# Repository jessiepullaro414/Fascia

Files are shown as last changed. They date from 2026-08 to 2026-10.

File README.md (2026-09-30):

# Fascia — KiCad schematic + PCB

Companion KiCad project for "Fascia", a 10-inch Android Automotive touch
display head unit: sibling to
[`manifold-pcb`](https://github.com/jessiepullaro414/Manifold),
[`thermo-pcb`](https://github.com/jessiepullaro414/Thermo) and `ecu-pcb`,
same 12V automotive constraints as the rest of the family.

Unlike the rest of the family this is a **two-board** project, because the
panel is physically detached from the main board and sits across the dash
from it:

1. **Carrier board** (behind the dash) — a Toradex Verdin iMX95 System on
   Module on a custom carrier: automotive 12V front end, LVDS display
   output via a DSI-to-LVDS bridge, backlight control, CAN FD to talk to
   `ecu-pcb`, line-level audio pre-outs to an external amplifier, a
   microphone input, and USB-C for wired CarPlay / Android Auto.
2. **Panel board** (in the bezel) — terminates the ribbon at the screen:
   panel LVDS connector, capacitive touch controller, backlight LED
   connector.

Bluetooth and Wi-Fi need no carrier hardware — they come with the
module's `WB` variant.

## Status

**PCB placed and routed to within 3 connections.**
`build_pcb.py` generates `Fascia.kicad_pcb`: 118 footprints, 574 pads
netted across 129 nets, six layers, on a **148 x 71 mm** board.
`route_board.py` (ported from the sibling boards) routes it with
FreeRouting, widens the power trunks, pours GND on In1 and In4, and then
asks `kicad-cli` DRC how many connections are really open. After a
150-pass run **3 connections are still unrouted**: `AOUT_RL_N` (codec to
the audio connector), `U9_ADR1_TIE`, and `LVDS_A_Y0N` (bridge to panel
connector). FreeRouting oscillated between 3 and 4 for the last 100
passes, so more passes of the same run will not close them; they need a
second stochastic attempt or hand-routing. `run_drc.py` reports
**schematic parity 0**, 12 `lib_footprint_mismatch` findings that are a
KiCad tooling artifact, and one silkscreen-over-mask finding.

Nothing about the differential pairs is tuned: FreeRouting does not
length-match, so the DSI and dual-link LVDS pairs are ordinary routed
nets with no impedance control. `route_board.py` prints the resulting
intra-pair skew so it is a number, not a guess.

Placement uses the **same skyline bottom-left packer as `manifold-pcb`
and `thermo-pcb`**, ported rather than reinvented, with three additions
this board needed:

- **Every part is tried both unrotated and rotated 90 degrees**, and goes
  wherever it yields the lowest resulting top edge. That is what turns
  the tall pin-header connectors on their sides and lets the 0603s
  backfill the low spots beside the big parts.
- **Keepouts are real packer inputs**, not checks applied afterwards.
- **The bridge, socket and panel connector are placed first** (`PIN_FIRST`
  in `build_pcb.py`), so the DSI-to-LVDS bridge sits beside the Verdin
  socket instead of 75 mm away. Area order alone had put it there, and
  nearly every open net in the first routing run was at that bridge.
- **A passive goes near its own IC** (`PULL`). Once its anchor IC is
  down, a passive takes the slot closest to it, with a height penalty so
  it cannot strand a void below. Plain lowest-gap order had put a
  pull-up 130 mm from the chip it belongs to. Estimated wirelength fell
  from 7,612 to 5,895 mm (`tools/placement_metric.py`), and FreeRouting
  at 12 passes went from 22 unrouted to 4.
- Spacing between parts (`CLEAR`) is 2.0 mm, up from 1.3. That alone took
  12-pass routing from 22 unrouted to 11, at a cost of 7 mm of height.

Group membership is derived from the netlist: each part joins whichever
IC or connector it shares the most **non-rail** nets with. Rails are
excluded deliberately: GND touches everything and would make every part
look equally related to everything else.

The Verdin socket is rotated 90 degrees as part of that. Its footprint is
36 x 79 mm, tall and narrow; on its side it is 79 x 36 mm and the board
becomes landscape, which is also the shape a dash opening wants.

**Schematic complete — every block wired except the backlight.**
`build_schematic.py` generates a real, KiCad-loadable schematic
containing the Verdin iMX95 X1 connector, the 12 V automotive front end,
the 5 V buck, the 1.8 V and 3.3 V rails, CAN FD, the SN65DSI85-Q1
DSI-to-LVDS bridge, the PCM3168A-Q1 audio subsystem with its level
shifters, the USB-C port, and the control/sequencing block. No PCB yet.

`kicad-cli sch erc` reports **10 violations**, and every one is either
blocked on a datasheet that has not arrived or deliberately optional:

| What | Count | Why it is still open |
| --- | --- | --- |
| `PWM_3_DSI`, `GPIO_10_DSI` | 2 | Backlight — needs the iFan string voltage and current |
| `USB_2_*` | 4 | Panel touch link — needs the panel's touch interface confirmed |
| `CAN_2_*` | 2 | Optional second CAN bus; no consumer chosen |
| `DSI_IRQ` | 1 | Bridge interrupt; wants a spare 1.8 V module GPIO |
| `IGN_SENSE` | 1 | Ignition sense; wants a module ADC input |

**160 pins carry real NoConnect items and 40 signal nets are wired.**

**Footprints are assigned and verified.** Every part maps to a real
footprint, and the build checks that each named file actually exists — a
mistyped library path is otherwise invisible until the netlist reaches
the PCB editor and silently drops the part.

### The LM61460-Q1 footprint is generated, not borrowed

TI's RJR0014A (VQFN-HR-14) has no KiCad library footprint, and it is not
something a generic QFN generator can produce: the pads are all different
sizes, unevenly spaced, and **the four corner pads are L-shaped**.

`tools/build_lm61460_footprint.py` builds it. The geometry is not
eyeballed off the drawing — the LAND PATTERN EXAMPLE on page 55 of TI
SNVSB70F is real vector art, so the pad rectangles were extracted from
the PDF's own path data and only the *scale* had to be inferred, from a
dimension the drawing states outright (pad 10 is 2.4 × 0.4 mm). That
scale then reproduced pad 10's 0.400 mm height exactly, which is what
makes the rest of the extraction trustworthy.

Each L-shaped pad is built from **two rectangles sharing one pad
number** — a real KiCad construction this project has met before, in a
Keystone fuse holder with two physical pads both numbered "1". It is far
safer than approximating an L with its bounding box, which would put
copper in the notch and eat the clearance to the neighbouring pads.

All four notches face the *outer* corner of the pattern, confirmed by
rendering the drawing around pads 1, 9 and 11 rather than assuming the
symmetry held.

The generator verifies itself twice: internally, that the pad table is
coherent (pin numbering, which pads are L-shaped, pad 10's dimensions,
overall extent, and that no two *different* pins overlap), and then by
**loading the result back through KiCad's own engine**. That second check
earned its place immediately — the first version emitted trailing
`; PINNAME` comments on the pad lines, and KiCad's s-expression format
has no comment syntax, so the whole library failed to load with nothing
more useful than "Unable to load library".

The Verdin module plugs into a standard DDR4 SODIMM socket, and KiCad's
`SODIMM-260_DDR4_H4.0-5.2_OrientationStd_Socket` has exactly 260 pads
numbered 1–260 — a direct match for the extracted pinout, so the biggest
footprint risk on this board turned out to be no risk at all.

### Exposed pads are three different decisions

Every one of these footprints numbers its exposed pad N+1 — 65 on the
TQFP-64s, 25 on the VQFN-24, 9 on the SON-8s. Each symbol therefore
carries an explicit `EP` pin, so what happens to that pad is a visible
decision on the schematic rather than an accident of the pad having no
net:

| Part | Exposed pad |
| --- | --- |
| **LM74930-Q1** | **NoConnect — must float.** The datasheet forbids grounding it |
| TLV767-Q1, TPS2557-Q1 | GND |
| SN65DSI85-Q1, PCM3168A-Q1 | GND (PowerPAD is reference ground) |

The LM74930-Q1's NoConnect is load-bearing: without an explicit pin,
that pad is merely netless, and nothing on the drawing would stop a
later ground-stitching pass from claiming it.

What is already final:

- all 260 X1 pins exist, banked into 6 units
- 47 GND pins tied to ground, 5 VCC pins tied to +5V
- 158 unused pins carrying real `NoConnect` items
- **LM74930-Q1 front end fully wired** — back-to-back FETs with `A` and
  `OUT` on the shared source node, sense resistor with its 50 Ω tap into
  `CS+`, `OVCLAMP` tied to `OV` for clamp-with-breaker rather than plain
  disconnect, and the OV/UVLO dividers, timer, ILIM and IMON networks
- **LM61460-Q1 5 V buck fully wired** — `BIAS` to the output rail (valid
  because Vout ≤ 12 V), boot network through `RBOOT`, FB and EN dividers,
  `RT`, and pull-ups on the open-drain `FLT` and `PGOOD` outputs
- **TLV767-Q1 1.8 V LDO wired** — an LDO rather than a buck on purpose:
  small load, and no switching noise added to a board carrying LVDS next
  to a car radio. This rail exists because the module's I/O is 1.8 V
  logic; it feeds the CAN transceiver's VIO now and the bridge later
- **TCAN1044V-Q1 CAN FD link wired** — split termination (2×60 Ω with a
  midpoint capacitor to ground, which shunts common-mode noise on a bus
  leaving the enclosure on a harness), separate 5 V VCC and 1.8 V VIO
  decoupling, and a pull-down on `STB` because the part's internal
  pull-up would otherwise wake it in standby
- the module's `CAN_1_TX` / `CAN_1_RX` now reach the transceiver
- **SN65DSI85-Q1 bridge wired** — DSI channel A in, both LVDS links out,
  all twelve VCC pins on 1.8 V, `VCORE` treated as the 1.1 V *output* it
  is with its 1 µF, `REFCLK` resistor-pulled to ground since the pixel
  clock comes from the D-PHY clock, `ADDR` strapped low, and the unused
  DSI channel B inputs plus both RSVD pins left genuinely unconnected
  with NoConnect items rather than tied off
- `J4` panel LVDS connector, **provisional** — carries all 20 LVDS
  signals, but its real pin order and pin count await the panel datasheet
- **PCM3168A-Q1 audio codec wired** — five differential pre-outs (front
  L/R, rear L/R, sub) to `J5`, microphone into the first differential ADC
  input, TDM on `DIN1`, `MODE` strapped low for the I2C control port
- **A 3.3 V rail and two SN74AXC4T245-Q1 level shifters**, because the
  codec's digital domain cannot be wired directly to the module — see
  "The audio block needs level shifters" below
- **I2C crosses domains through the classic two-FET translator** rather
  than a push-pull part, which cannot pass an open-drain bus
- **USB-C port wired** — TPS2557-Q1 switching VBUS with a ~3.3 A limit,
  Rp resistors on both CC pins advertising 3 A from a downstream-facing
  port, ID strapped low for host mode, a divided VBUS sense back to the
  module, and ESD on every pin a passenger can touch. No PD controller
  and no negotiation firmware.
- **Control and sequencing wired** — JTAG header, power/recovery/reset
  buttons, and the RTC coin cell behind the ≥47 kΩ current-limiting
  resistor the datasheet requires (a lower value can stop the module
  booting). `CTRL_PWR_EN_MOCI` now gates the 1.8 V and 3.3 V LDOs, so
  the carrier rails follow the module instead of racing it at power-on.
- every pin on all nine ICs either netted or explicitly NoConnected

### The generator checks for silently merged nets

Blocks are laid out independently, so two can drift into the same region
and land one net's stub endpoint exactly on another's. That **merges the
two nets** — electrically catastrophic and near-invisible on the drawing.
It happened twice while building this schematic:

1. a codec decoupling cap's ground stub landed on the power tree's
   `UVLO_DIV` label;
2. the USB block's `USB_ILIM` stub landed on connector unit D's
   `USB1_VBUS_SENSE` stub.

ERC does report this as `multiple_net_names`, but only for the pair it
happens to notice and only after the fact. `build_schematic.py` now
records every terminated coordinate — pin positions *and* stub
endpoints, for both generic parts and the X1 connector — and fails
loudly, naming both nets and both owning references. The first version
of that check scanned only label positions and missed the second case
entirely, which is why it now tracks points rather than labels.

### The audio block needs level shifters (and why that is not optional)

The PCM3168A-Q1 has two supply domains: analog VCC at 4.5–5.5 V and
**digital VDD at 3.0–3.6 V**. VDD cannot be run at 1.8 V, so the codec
cannot share the module's logic level. Reading the electrical table
makes the consequence sharper than "it needs a translator":

| | Codec | Verdin |
| --- | --- | --- |
| Input high, min | **2.0 V** | drives 1.8 V max |
| Output high, min | **2.4 V** | **2.1 V absolute maximum** |

The first row means the module cannot reliably drive the codec. The
second row is the dangerous one: the codec's output high is *above the
module's absolute maximum rating*. Wired directly, the codec-to-module
direction would not merely fail — it would damage the module.

So every digital line between them is translated: I2S and the clocks
through SN74AXC4T245-Q1 translators, and I2C through the classic
two-N-FET open-drain circuit, because a push-pull translator cannot pass
a bus where either end may pull low.

What exists right now:

- `tools/extract_verdin_pinout.py` — extracts the full 260-pin Verdin
  iMX95 X1 connector pinout from Toradex's own hardware datasheet.
- `verdin_pinout.py` — the generated result: all 260 pins, 47 GND, 5 VCC,
  and the 20 LVDS pins, cross-checked against a second independent table
  in the same document.
- `verdin_x1.py` — functional banking of those 260 pins into multi-unit
  symbol units, with a verifier that proves the banking is a true
  partition of the connector.
- `build_schematic.py` — generates `Fascia.kicad_sch`, `Fascia.kicad_sym`,
  `sym-lib-table` and (on first run only) `Fascia.kicad_pro`.

Three things that were needed to get the first ERC pass down from 268
findings to the real ones, recorded because each cost a debug cycle:

1. **Power symbols must touch the net graphically.** A power symbol's own
   pin sits at its local origin with zero length, so placing it *near* a
   connector pin leaves both dangling — 155 `pin_not_connected` findings.
   The fix is a short stub wire from the pin out to the symbol, which
   also keeps the symbol graphic off the pin name.
2. **PWR_FLAGs need the same graphical reachability.** A flag placed in
   isolation, relying on name-based net merging, does not satisfy
   `power_pin_not_driven` (54 findings). Placing each flag on a real
   point of its net clears it.
3. **`kicad-cli` needs a `.kicad_pro` to resolve `${KIPRJMOD}`.** Without
   one it cannot find the project-local `sym-lib-table` and reports one
   `lib_symbol_issues` warning per placed symbol (60 findings), even
   though the symbols are embedded in the schematic and perfectly valid.

Everything below the "Design decisions" section is a plan, not a
description of something that exists. See "Known open items".

### Why X1 is banked into units

A 260-pin connector cannot be one schematic symbol — at 2.54 mm pitch a
single block is ~330 mm tall, taller than any sheet this project uses.
KiCad's answer is a multi-unit symbol, so `verdin_x1.py` assigns each pin
to a unit based on how *this board* uses the connector:

| Unit | Pins | Contents |
| --- | --- | --- |
| A | 55 | Power and ground |
| B | 16 | Control, sequencing, JTAG, tamper |
| C | 15 | Display — the DSI link to the bridge, plus backlight control |
| D | 16 | Communications — CAN to `ecu-pcb`, I2C, USB 2.0 for touch |
| E | 158 | Unused on this board (gets NoConnect items) |

Banks are derived from pin *names* rather than hand-listed pin numbers,
so re-running the extractor against a newer datasheet revision cannot
silently desynchronise the two files. That only works if the rules stay
exhaustive, which `verify()` enforces: every pin exactly once, nothing
invented, nothing dropped, plus explicit assertions on the two groupings
most worth getting right —

- the **display bank** must be exactly the 15 pins from datasheet
  Table 22, asserted by number rather than trusted to a pattern;
- the **USB split** must put the USB 2.0 data pair in the comms bank and
  SuperSpeed in the unused bank. This board's only USB is a 2.0 host port
  for the panel's touch controller, so the SS pairs are unused *on
  purpose*. Worth an explicit rule because they appear under two
  different naming styles — Verdin-standard `USB_2_SS*` and
  module-specific `USB1_TX1_*`/`USB1_RX1_*` — and a single `USB_` pattern
  silently catches one and misses the other.

Bank E is not filler. Per this project's KiCad notes a deliberately
unused pin needs a real `NoConnect` item, not a stub label, or ERC
reports it as a dangling/isolated label — so the unused pins have to be
enumerated as carefully as the used ones.

## Why this SoC, and why not the one I started with

The project began as "10-inch Android Automotive display on an NXP
i.MX 93". **The i.MX 93 cannot run Android**, and this was worth catching
before any board work started:

- The i.MX 93 has no 3D GPU — only the PXP 2D pixel pipeline.
- Since Android 10, NXP has excluded GPU-less i.MX parts from Android
  support outright, because Android's GPU and extension requirements
  can't be met. Running it would mean maintaining a private Android fork
  on software rendering.
- NXP's current i.MX Android BSP covers the 8M Mini/Nano/Plus/Quad, 8ULP,
  8QuadMax/XPlus and i.MX 95. Not the 93.

Replaced with the **i.MX 95**, which has an Arm Mali-G310 (OpenGL ES 3.2,
Vulkan 1.2, 2D+3D), is on NXP's Android BSP list, and is automotive
qualified.

### Why a SoM instead of a raw i.MX 95

A raw i.MX 95 is a 19×19 mm BGA paired with LPDDR5. That forces HDI
construction (laser microvias, blind/buried vias, 12–14 layers just to
escape the BGA) and roughly 90 length- and skew-matched LPDDR5 nets.

That last part is the disqualifier for this project specifically:
FreeRouting cannot do length-matched differential DDR routing, so the DDR
work would have to be manual — which directly contradicts this family's
rule that the generator scripts are the source of truth and the board is
always regenerated, never hand-edited.

Putting the SoC on a **Toradex Verdin iMX95** module moves the LPDDR5 and
its HDI stackup onto a part Toradex has already qualified, and leaves a
carrier board that is connectors, power and differential pairs — squarely
inside what the existing generate → route → verify pipeline handles.

## Design decisions

### Display link: 1920×1200, DSI-to-LVDS bridge on the carrier

The panel is detached and 20 cm–1 m away across the dash, so the link
that crosses that gap must be **LVDS** — differential and low-swing, so
it survives alternator and ignition noise. Options for the long run:

| Option | Verdict |
| --- | --- |
| **LVDS over shielded FFC** | **Chosen for the cable run.** Robust over a dash-length ribbon, and what 10.1" panels natively accept. |
| MIPI DSI direct to the panel | Rejected. D-PHY is designed for on-PCB or very short flex (~15–20 cm); unshielded ribbon across a dash is an EMI problem. |
| HDMI | Not native on the module. Needs a DSI-to-HDMI bridge on the carrier *and* a receiver board behind the panel bridging back. Two extra bridges. |
| FPD-Link III / GMSL2 | The right answer for genuinely long runs (10 m+), overkill and expensive here. |

**How the LVDS gets generated is the part that took real work.**

The module's own display ceilings, from datasheet Table 3: **LVDS 1× up
to 1920×1080**, **MIPI DSI 1× quad lane up to 4K**.

The 10.1" panel market is overwhelmingly **16:10** (1280×800 and
1920×1200), not 16:9. 1920×1200 needs ~154 MHz of pixel clock, which is
**above the module's 1920×1080 native LVDS ceiling** — both Toradex and
NXP's summary cap i.MX 95 LVDS at 1080p60. Forum figures of 170 MHz for
dual-channel split mode are **i.MX 6**, a different generation, and must
not be extrapolated to this part.

So: take **MIPI DSI off the module** (where 1920×1200 is far inside the
4K ceiling) and convert to dual-channel LVDS **on the carrier board**,
right at the ribbon connector, with a **TI SN65DSI85-Q1** — AEC-Q100
qualified, dual-channel LVDS out, 24 bpp, pixel clock 25–154 MHz.

The DSI run stays on-PCB where D-PHY is happy (centimetres); the long,
noisy dash run is still LVDS. Cost is one bridge IC.

**The module's native LVDS pins (88–144) are therefore unused.** They
remain documented in `verdin_pinout.py` in case the design ever falls
back to 1080p native.

**Unexpected benefit:** the whole DSI pin group sits on Verdin-standard
*Reserved* pins (17–55) rather than the *Module-specific* pins native
LVDS uses. This design is therefore **more** portable to other Verdin
modules than the native-LVDS version would have been — it inverts the
portability caveat noted below.

**Confirmed DSI pin group** (Verdin iMX95 datasheet Table 22), which
carries not just the lanes but every control signal the bridge and
backlight need:

| X1 pin | Signal | Role |
| --- | --- | --- |
| 23 / 25 | DSI_1_D3_N / _P | DSI data lane 3 |
| 29 / 31 | DSI_1_D2_N / _P | DSI data lane 2 |
| 35 / 37 | DSI_1_CLK_N / _P | DSI clock |
| 41 / 43 | DSI_1_D1_N / _P | DSI data lane 1 |
| 47 / 49 | DSI_1_D0_N / _P | DSI data lane 0 |
| 53 / 55 | I2C_2_DSI_SDA / SCL | SN65DSI85-Q1 configuration |
| 17 | GPIO_9_DSI | bridge enable |
| 19 | PWM_3_DSI | backlight brightness |
| 21 | GPIO_10_DSI | backlight enable |

### SN65DSI85-Q1: confirmed from the TI datasheet (SLLSEJ4B)

The mode this whole design depends on is **explicitly supported** —
datasheet Table 5, "Single DSI Input to Dual-Link LVDS":

> Single DSI Input on Channel A to Dual-Link LVDS output with Odd pixels
> on Channel A and Even pixels on Channel B.

Register configuration for that mode:

| CSR | Field | Value |
| --- | --- | --- |
| 0x10.6:5 | `DSI_CHANNEL_MODE` | `01` — single-channel DSI receiver |
| 0x10.4:3 | `CHA_DSI_LANES` | `00` — four lanes enabled |
| 0x18.4 | `LVDS_LINK_CFG` | `0` — dual-link LVDS |
| 0x18.3 | `CHA_24BPP_MODE` | `1` — 24 bpp |
| 0x18.1 / 0x18.0 | `CHA/CHB_24BPP_FORMAT1` | selects Format 1 vs Format 2 |

Other confirmed facts that drive the schematic:

- **AEC-Q100 Grade 2, −40 °C to +105 °C ambient.** Better rated than the
  Verdin module itself, and consistent with the rest of this family.
- **Single 1.8 V supply** (VCC 1.65 / 1.8 / 1.95 V). No second rail.
- **HTQFP-64 (PAP)** with thermal pad. RθJA 36.1 °C/W, max case
  temperature 92.2 °C — the pad needs a real thermal via field.
- **REFCLK (pin 17) is optional** — the LVDS pixel clock can be sourced
  from the free-running D-PHY clock instead. If unused it **must be
  pulled to ground through an external resistor**, not left floating.
- **ADDR (pin 64)** selects the I2C target address; if strapped high it
  must go to the *same* 1.8 V rail as VCC, not any other 1.8 V source.
- **IRQ (pin 33)** is an interrupt output back to the SoC.
- **EN** may be driven by `GPIO_9_DSI` or by an RC (≈200 kΩ + ≈200 nF).
  It must only go high *after* VCC is valid. To reset with VCC already
  high, EN must be held low ≥10 ms.
- **Sequencing constraint for the driver:** the DSI CLK lane must be in
  HS and the DSI data lanes driven to LP11 while the device is in reset,
  before EN is asserted.
- For 18 bpp the `Y3` pairs are left NC; at 24 bpp all four data pairs
  per link are used — so the panel connector carries 10 pairs.
- `CHA_SYNC_DELAY` must be programmed to at least 32 pixel clocks.

**Everything is configured over I2C — there is no format strapping.**
That is a meaningful de-risking result: the VESA-versus-JEIDA mapping
question is a *software* choice (`24BPP_FORMAT1`), so picking the panel
later cannot force a board respin over it.

### Timing margins — corrected

An earlier revision of this file claimed 1920×1200 sat "exactly at the
bridge's 154 MHz ceiling". **That was wrong**, and the error mattered:
the 25–154 MHz figure is the **LVDS output clock per link**, and in
dual-link mode each link carries half the pixels. TI's own power-table
reference case is literally 1920×1200 dual-link with
**LVDS CLK OUT = 81.6 MHz**.

The real picture, with every number now confirmed against a primary
source:

| Constraint | Value | Limit | Utilisation |
| --- | --- | --- | --- |
| i.MX 95 DSI transmit, per lane | ~925 Mbps | **2500 Mbps** | **~37% — huge headroom** |
| LVDS output clock, per link | ~81.6 MHz | 154 MHz | ~53% — comfortable |
| **Bridge DSI input, per lane** | ~925 Mbps | **1 Gbps** | **~93% — the bottleneck** |

The i.MX 95 side is confirmed a non-issue: **IMX95AEC Rev 8, Table 58,
`RATE[TX]` Transmit Serial Data Rate = 80 to 2500 Mbps per lane**, and
the feature summary lists "1x 350 MHz MIPI-DSI (4-lane, 2.5 Gbps/lane)
supporting 4kp30 or 3840 x 1440p60".

So the **SN65DSI85-Q1 is the sole bottleneck** in the chain. That is
acceptable — TI documents 1920×1200 as a supported use case for this
part — but it means the bridge, not the SoC, is what to re-examine if
the timing ever fails to close.

The same datasheet confirms the native LVDS ceiling recorded above:
"2x 1080p60 LVDS Tx (2x 4-lane or 1x 8-lane)".

- 1920×1200p60 CVT-RB ≈ 154 MHz pixel clock × 24 bpp = ~3.70 Gbps across
  4 lanes = ~925 Mbps/lane. Under the bridge's 1 Gbps limit, with ~7%
  headroom.
- With **standard** (non-reduced) blanking the pixel clock is ~193 MHz →
  ~1.16 Gbps/lane, which **exceeds** the bridge limit (though not the
  SoC's). Reduced-blanking timing is therefore mandatory, not merely
  preferable.
- Fallback remains 1920×1080, which relaxes the DSI side to
  ~830 Mbps/lane.

### Layout constraints (i.MX 95 Hardware Design Guide UG10210 Rev 2.0)

- **100 Ω differential** for MIPI DSI *and* LVDS, ±10% (Table 40). Also
  50 Ω single-ended for everything else unless specified. This sits
  comfortably inside the SN65DSI85-Q1's own 90–132 Ω LVDS output range.
- For MIPI-DSI compliance tests 1.1.4/1.1.5, keep **parasitic
  capacitance of each DSI trace below 10 pF** — relevant because the DSI
  run crosses the carrier from X1 to the bridge.
- The module's unused native LVDS pins are simply left **not connected**
  (datasheet Table 4). The `VDD_LVDS_1P8`-to-ground-via-10 kΩ guidance in
  that same table applies to the SoC, which is Toradex's side of the
  boundary, not this carrier's.

Note the Verdin carrier must still follow Toradex's own Carrier Board
Design Guide (doc 108140) for anything X1-side; UG10210 describes the
raw SoC.

For reference, the module's native LVDS pins, should the fallback be
needed:

| X1 pin | Channel 0 | X1 pin | Channel 1 |
| --- | --- | --- | --- |
| 88 / 90 | LVDS0_CLK_N / _P | 118 / 120 | LVDS1_CLK_N / _P |
| 94 / 96 | LVDS0_D0_N / _P | 124 / 126 | LVDS1_D0_N / _P |
| 100 / 102 | LVDS0_D1_N / _P | 130 / 132 | LVDS1_D1_N / _P |
| 106 / 108 | LVDS0_D2_N / _P | 136 / 138 | LVDS1_D2_N / _P |
| 112 / 114 | LVDS0_D3_N / _P | 142 / 144 | LVDS1_D3_N / _P |

### Candidate panels evaluated

Real parts found, with the specs that actually drive the board design:

**Selected: iFan IF101GRL192-120B** (2026-08-16), pending the vendor
datasheet and pricing. Chosen mainly on temperature — it is a full 10 °C
better at both ends than the other 1920×1200 candidate, which is the
difference between reliable and marginal on a sun-baked dash — with 89%
DCI-P3 gamut as a real bonus for image quality.

<https://ifan-display.com/product/10-1-inch-touch-panel-1000-nits-wide-color-gamut-1920x1200/>

| Part | Res | Nits | Interface | Touch | Bonded | Temp |
| --- | --- | --- | --- | --- | --- | --- |
| **iFan IF101GRL192-120B** ← selected | 1920×1200 | 1000 | LVDS, 60-pin | **PCAP inc.** | ? | **−30 to +80 °C** |
| Riverdi RVT101HVLNWC00-B | 1280×800 | ~1000 | LVDS | PCAP inc. | **yes** | industrial |
| CDTech S101BWU78EP | 1920×1200 | 1000 | LVDS, 45-pin FPC | no | no | −20 to +70 °C |
| CDTech S101HWX101ED | 1280×800 | 1000 | 4-lane LVDS, 40-pin FPC | no | no | −30 to +80 °C |
| CDTech S101HWX80NP-FC81 | 1280×800 | 350 | 1-ch LVDS, 30-pin | ILI2511 (USB) | no (G+G) | −20 to +70 °C |
| AUO G101UAN02.0 | 1920×1200 | 800 | **MIPI** | no | no | **−10 to +60 °C** |

**The market bifurcates, and neither half is the full target spec:**

- You can get **1920×1200 + 1000 nit + touch** (iFan), but optical
  bonding is unconfirmed and there is no public datasheet — it is a
  contact-the-vendor part.
- Or you can get **productized optical bonding + PCAP + real datasheets
  + distributor stock** (Riverdi), but only at 1280×800.

The full combination is realistically a **semi-custom order with MOQ**,
not an off-the-shelf purchase.

AUO's G101UAN02.0 is ruled out on two counts despite being the obvious
1920×1200 name: it is **MIPI, not LVDS** (which would put D-PHY on the
dash ribbon, the thing this whole design avoids), and −10 to +60 °C is
unusable in a car.

Three things to carry forward:

1. **The backlight boost designs are not interchangeable** — 27–34 V at
   240 mA versus 13.5–17 V at 360 mA versus 5 V at 530 mA are three
   different converters. The panel must be chosen before the backlight
   circuit is designed. iFan publishes only a total figure (9.32 W), so
   the string configuration has to be asked for.
2. **Temperature does not track resolution.** CDTech's 1920×1200 part is
   −20 to +70 °C while their 1280×800 is −30 to +80 °C. A dash bakes in
   sun, so this is a real selection criterion, not a footnote — it is the
   main reason the iFan part leads.
3. **Touch is often USB, not I2C.** Both CDTech modules with touch use
   USB controllers (ILI2511), and iFan lists "USB/I2C". This matters —
   see below.

### Touch interface: USB may beat I2C over this cable run

The original plan assumed I2C touch. The market says otherwise, and on
reflection USB is probably the better engineering choice here anyway:

- **I2C is single-ended** and was designed for on-board use. Over 20 cm
  it is fine; over a metre it is marginal — bus capacitance eats the
  rise time and there is no noise rejection in a car's environment.
- **USB is differential and designed for cables.** A metre is nothing.
  It also arrives as a standard HID device, so Android needs no custom
  touch driver or device-tree work.
- Cost is one differential pair on the ribbon instead of two
  single-ended wires, and a USB host port on the carrier — which the
  Verdin already has.

Decision still open, but it should be made on cable length, not on
which is simpler on paper.

### Power tree and part selection

Every part below was verified against its own datasheet, not chosen from
memory. Two of them corrected an earlier wrong guess, noted inline.

| Role | Part | Key evidence |
| --- | --- | --- |
| Front-end protection | **LM74930-Q1** | AEC-Q100 grade 1 (−40/+125 °C), 4–65 V in, reverse protection to −65 V, adjustable OC/OV, circuit breaker, "meets automotive ISO7637 transient requirements with a suitable TVS diode" |
| 12 V → 5 V buck | **LM61460-Q1** | AEC-Q100 grade 1, 3–36 V in (42 V transient), 6 A, synchronous, low-EMI with spread spectrum |
| CAN FD | **TCAN1044V-Q1** | AEC-Q100 grade 1, VIO 1.7–5.5 V with explicit 1.8 V support, CAN FD to 8 Mbps, ±58 V bus fault protection |
| DSI→LVDS bridge | **SN65DSI85-Q1** | AEC-Q100 grade 2 (−40/+105 °C), single 1.8 V rail, HTQFP-64 |
| Audio codec | **PCM3168A-Q1** | AEC-Q100, 24-bit 6-in/8-out codec, differential outputs, I2S/TDM, 104 dB, 64-HTQFP |
| USB VBUS switch | **TPS2557-Q1** | Automotive, current limit adjustable 500 mA–5 A, FAULT output, dual thermal sensing |
| Wi-Fi / Bluetooth | **on-module** (u-blox MAYA-W260-00B) | Wi-Fi 6, Bluetooth Classic/LE 5.4, two U.FL connectors — comes with the Verdin `WB` variants |

**The module sets two hard constraints** that drove these choices:

- **VCC is 3.135–5.5 V**, so the main rail is 5.0 V.
- **Verdin I/O is 1.8 V logic** (absolute max 2.1 V). This is the
  constraint that eliminates most automotive CAN transceivers.

#### Front-end topology (resolved from the datasheet, not inferred)

TI's own front-page reference circuit for the LM74930-Q1 is titled
**"VBAT 12-V or 24-V With 200-V Unsuppressed Load Dump — Output Clamp"**.
That is this application almost exactly: an unsuppressed alternator on a
1972 car, with the output clamped rather than disconnected.

The back-to-back FET arrangement is easy to get backwards, so it is
written down here:

```
VBAT ──[RSENSE]──┬── Q2 drain            Q2 = pass / load switch  (HGATE)
                 │                       Q1 = ideal diode         (DGATE)
                 Q2 source ──┬── COMMON ──┬── Q1 source
                             │            │
                        OUT (15)      A (2)      ← both pins on COMMON
                                                    (common-source pair)
                                       Q1 drain ── VOUT_PROT ── C (24)
```

The resolution: **`A` (2) and `OUT` (15) are the same node.** "Back-to-back
N-channel MOSFETs in common source configuration" means both FET sources
tie together, and the datasheet independently says `A` is "the source of
the external ideal diode MOSFET" while `OUT` is "the common source rail".
`C` (24) is the ideal diode's drain and therefore the protected output.
Direction is confirmed by the ideal-diode spec regulating "10.5 mV **A to
C** forward voltage drop", and by `HGATE` driving "the **first** MOSFET in
the power path".

Reference-design support components, all named in that circuit: `RSENSE`
with `RSET` (50 Ω into `CS+`), `RISCP` on `ISCP`, `RILIM` on `ILIM`,
`RMON` on `IMON`, `CT` on `TMR`, `CVS` on `VS`, `CCAP` across `CAP`–`VS`,
and the `R1`/`R2`/`R3` dividers feeding `OV`/`OVCLAMP` and `UVLO`.

#### The 5 V rail needs splitting

Rough budget, with the module figure still a placeholder:

| Load | Estimate |
| --- | --- |
| Verdin iMX95 | ~3 A @ 5 V (unknown — see open items) |
| USB-C charging | 3 A @ 5 V |
| Bridge, codec, CAN, misc | ~0.5 A |
| **Total on 5 V** | **~6.5 A** |

That is over the LM61460-Q1's 6 A, so **two supplies** rather than one
bigger one: a main rail for the module and peripherals, and a second
dedicated to USB VBUS. Splitting is the better design anyway — a phone
drawing a fault current should not be able to brown out the SoC and
reboot Android. Using the same part twice also keeps the BOM narrow.

The backlight boost is deliberately *not* on the 5 V rail — it runs from
the protected 12 V directly, since the panel wants ~27–34 V and routing
that through 5 V would waste a conversion and eat the budget.

#### Bluetooth comes free with the module

The Verdin `WB` variants carry a u-blox **MAYA-W260-00B**: Wi-Fi 6,
**Bluetooth Classic / LE 5.4**, IEEE 802.15.4, and **two U.FL antenna
connectors already on the SoM**. That means no RF design, no antenna
matching and no radio certification work on this carrier — just two U.FL
cables out to external antennas.

Bluetooth Classic covers A2DP for streaming and HFP for hands-free calls.
Wi-Fi plus Bluetooth together is also exactly what **wireless CarPlay and
Android Auto** need, so the USB-C port is for wired mode and charging
rather than being the only way in.

Cost to record: the datasheet carries separate pin tables for "modules
without Wi-Fi", so the `WB` variant consumes some UART and ADC pins that
would otherwise reach the carrier. The variant has to be locked before
the connector banks are final.

#### Two corrections worth recording

**The CAN transceiver must be the `V` variant.** An earlier draft of this
plan named the TCAN1043-Q1, which only level-shifts to 3.3 V or 5 V — it
cannot talk to 1.8 V logic at all. Worse, within the correct family the
datasheet's own device comparison table reads:

| Part | Low-voltage I/O support on pin 5 |
| --- | --- |
| TCAN1044-Q1 | No — pin 5 is a No-Connect |
| **TCAN1044V-Q1** | Yes — pin 5 is VIO, 1.8–5.5 V |

The suffix is the entire difference. Order the wrong one and the board
assembles perfectly and the CAN link never works.

**The surge stopper is TI's, not the obvious ADI part.** The LTC4364 is
the better-known automotive surge stopper and does something the
LM74930-Q1 does not — it *regulates through* an overvoltage event rather
than disconnecting. But its datasheet order table lists only C, I and H
temperature grades with **no AEC-Q100 qualification**, which fails this
family's standard (see `ecu-pcb`, where the last unqualified part was
deliberately swapped out). The LM74930-Q1 is explicitly `-Q1`.

**Correction — the LM74930-Q1 does clamp through.** An earlier revision
of this file claimed it protects only by disconnecting the load, and
warned that a load dump would therefore collapse the 5 V rail and force
an Android reboot. That was wrong, and reading the pin table and spec
table settled it:

- pin 16 is **`OVCLAMP`**: "connect this pin to OV pin for overvoltage
  clamp with circuit breaker (timer) functionality";
- `OVCLAMP` has its own rising/falling thresholds (0.59 V / 0.45 V),
  separate from the plain `OV` disconnect thresholds;
- the timer spec includes **`I(TMR_SRC_OVCLAMP)`, "TMR source current
  during overvoltage clamp"** — a dedicated clamp state, not a
  disconnect;
- and `N(A_R_Count)` gives **32 auto-retry cycles**.

So it regulates the pass FET through an overvoltage event for a period
set by the TMR capacitor, then opens the breaker if the event outlasts
it, then auto-retries. That is genuine surge-stopper behaviour, and it
removes the reboot risk previously recorded here.

What remains real is that the clamp is **timed, not indefinite**: the TMR
capacitor has to be sized to ride out a 200 ms load dump, and the pass
FET has to survive dissipating it for that long. FET SOA selection is
therefore a genuine design task — see "Known open items".

For scale, the LTC4364 datasheet gives the industry-standard transient
shapes: a general automotive transient of tr = 10 µs / VPK = 80 V /
τ = 1 ms, and **load dump of tr = 5 ms / VPK = 60 V / τ = 200 ms**. The
200 ms one carries the energy that matters.

### Panel quality matters more than resolution here

Recorded because it should drive the panel budget. In a car, in rough
order of impact on how good the display actually looks:

1. **Brightness** — consumer panels (250–400 nits) wash out in direct
   sun; automotive panels run 800–1500 nits. This is the dominant factor
   and it drives the backlight boost design (string current, thermals).
2. **Optical bonding** (OCA/LOCA) — removes the air gap between LCD and
   cover glass that otherwise destroys daylight contrast; also prevents
   condensation.
3. **24-bit colour, not 18-bit** — 6-bit-per-channel LVDS panels band
   visibly on the dark gradients Android Automotive uses.
4. **IPS** — driver and passenger both view well off-axis.
5. **Anti-glare / AR coating.**

Resolution ranks below all of these. The target spec is a 1080p,
~1000-nit, optically-bonded, 24-bit IPS panel.

**Caveat worth recording:** LVDS on Verdin is a *Module-specific*
function, not an Always-Compatible or Reserved one (datasheet Table 6
classifies it `Total 1 / Always Compatible 0 / Reserved 0 /
Module-specific 1`). The pins are genuinely on the connector, but this
carrier is therefore tied to the Verdin iMX95 specifically and is not
portable to an arbitrary other Verdin module. MIPI DSI, by contrast, sits
on Verdin-standard Reserved pins (17–55) and would be portable — at the
cost of needing a bridge for a dash-length run.

This is also why `tools/extract_verdin_pinout.py` exists rather than a
hand-typed table: the LVDS pins are named `MSP_1`…`MSP_25` in the Verdin
specification column and only resolve to `LVDS0_CLK_N` etc. in the
module-specific function column. A parse that reads the wrong column
concludes the module has no LVDS at all.

### Other confirmed module facts

- Module: 69.6 × 35.0 × 6.0 mm, 260-pin DDR4 SODIMM edge connector.
- Odd pins top side, even pins bottom (DDR4 SODIMM numbering).
- 5 VCC pins (251, 253, 255, 257, 259), 47 GND, plus `VCC_BACKUP` (249).
- CAN FD: `CAN_1_TX`/`CAN_1_RX` on pins 20/22, `CAN_2` on 24/26.
- I2C_1 on pins 12/14; a dedicated display-side `I2C_2_DSI` on 53/55.
- Backlight: `PWM_3_DSI` (pin 19) for brightness, `GPIO_10_DSI` (pin 21)
  for backlight enable via the on-module PCAL6416A I/O expander.
- HDMI is explicitly *not* natively supported on this module.

## Planned scope

A head unit that **displays and sources audio but does not amplify it**.
Scope revised 2026-08-16 from the original display+touch+CAN.

In scope: display, touch, CAN to `ecu-pcb`, Bluetooth, line-level
pre-outs to an external amplifier, a microphone for calls and voice
control, and USB-C for wired CarPlay / Android Auto plus phone charging.

Explicitly **not** in scope: any power amplifier. This board drives no
speakers — it feeds an existing automotive amp over RCA-level pre-outs.
That single decision keeps the highest-current, highest-heat, highest-EMI
subsystem off the board entirely, which matters in a sealed dash
enclosure that already contains a 1000-nit backlight.

Also still out of scope: reversing camera, automotive Ethernet, and any
radio tuner.

Carrier board blocks:

- 12V automotive front end: reverse-polarity protection, load-dump
  clamping (ISO 7637-2 pulse 5), wide-Vin buck to the module rails.
- Verdin X1 260-pin SODIMM socket.
- Module power sequencing: `CTRL_PWR_EN_MOCI`, `CTRL_RESET_MOCI#`,
  `CTRL_SLEEP_MOCI#`, ignition/ACC sense.
- MIPI DSI from X1 into a **SN65DSI85-Q1** bridge — short, impedance-
  controlled, length-matched on-board runs; the bridge sits right at the
  panel connector so the DSI never reaches the ribbon.
- Bridge configured over `I2C_2_DSI`, enabled by `GPIO_9_DSI`.
- **Audio: PCM3168A-Q1 codec** on I2S/TDM from the module. Five of its
  eight DAC channels drive the pre-outs (front L/R, rear L/R, mono sub);
  one ADC channel takes the microphone. Differential outputs, which is
  the right choice for running line level across a car to an amp.
- **Microphone connector** for a remote mic mounted near the A-pillar or
  headliner, with bias. Placement beats mic quality in a car by a wide
  margin, which is why it is off-board.
- **USB-C port** for wired CarPlay / Android Auto: USB 2.0 data to the
  module's `USB_1` port, and VBUS from a **TPS2557-Q1** switch whose EN
  and FAULT map onto `USB_1_EN` and `USB_1_OC#`. CC1/CC2 carry Rp
  resistors advertising 3 A as a downstream-facing port — no PD
  controller and no negotiation firmware.
- Two **U.FL antenna** pigtails from the module's on-board wireless out
  to external Wi-Fi/Bluetooth antennas.
- Dual-channel LVDS out of the bridge to the panel connector, with
  common-mode chokes and ESD protection on each of the 10 pairs.
- Backlight boost driver, PWM-dimmed via `PWM_3_DSI`, enabled by
  `GPIO_10_DSI`, sized for a high-brightness (~1000 nit) panel rather
  than a consumer-grade one.
- CAN FD transceiver to `ecu-pcb`.

Panel board blocks:

- Ribbon connector from the carrier.
- Panel LVDS FFC connector — pin count set by the chosen panel (the
  leading candidate uses 60-pin).
- Capacitive touch controller — must live at the panel, since capacitive
  sensing will not tolerate a metre of cable between controller and
  sensor. Most candidate modules integrate it already. Interface back
  down the ribbon is **USB or I2C, still to be decided** (see "Touch
  interface" above).
- Backlight LED string connector.

## How it's built

Same script-driven, kiutils/kicad-cli-verified workflow as the sibling
projects: the generator scripts are the source of truth — always
regenerate from them, never hand-edit `Fascia.kicad_sch`/`Fascia.kicad_pcb`
directly.

`tools/extract_verdin_pinout.py` is a one-shot data extractor, not part of
the per-build pipeline. It takes the Toradex datasheet's local path as an
argument (the PDF is Toradex's document and is gitignored, not committed):

```bash
python tools/extract_verdin_pinout.py ~/Downloads/200007-verdin_imx95_datasheet.pdf
```

It refuses to write output unless all 260 pins parse and the LVDS pin
numbers it derived from the main pin-assignment tables agree with the
separate LVDS table on page 42.

## Known open items

- No BOM or fab outputs yet. See [PLAN.md](PLAN.md) for the full list of
  what is left and what each step is blocked on.
- **Panel selected but its datasheet is not yet in hand.** The
  **iFan IF101GRL192-120B** is chosen; a request for datasheet and
  pricing went to the vendor on 2026-08-16. Until it arrives, anything
  that depends on the panel's real numbers is blocked:
  - the backlight boost converter (no string V/I published)
  - the panel-side connector footprint and pinout (60-pin, mapping
    unknown)
  - the touch link (USB vs I2C, see above)
  - bezel/mechanical
- **Questions to put to iFan** — none are answerable from their public
  page:
  - Is optical bonding available, and at what MOQ?
  - LVDS single or dual channel? (1920×1200 at 24 bpp requires dual, so
    this is really a confirmation, but the 60-pin connector needs a
    pinout either way.)
  - Backlight string configuration — volts and milliamps, not just the
    published 9.32 W total. The boost converter cannot be designed
    without it.
  - Touch controller IC, and is the interface USB or I2C?
  - Connector part number, and is a mating FFC/cable available?
  - Operating temperature is quoted as −30 to +80 °C; confirm storage
    range and whether an automotive-qualified variant exists.
- **Touch interface undecided** — USB versus I2C, see the section above.
  Leaning USB on cable-length grounds.
- **DSI timing closes on paper but is not yet proven on hardware.** Every
  number in the chain is now confirmed against a primary source and
  1920×1200 fits, but with only ~7% headroom on the bridge's DSI input
  and a hard requirement for reduced-blanking timing. Worth confirming on
  a Verdin EVK with the real panel before committing to fab. Fallback is
  1920×1080.
- **LVDS mapping convention not yet fixed** — VESA vs JEIDA (a.k.a. SPWG)
  differ in bit ordering and are not interchangeable. Determined by the
  chosen panel.
- **Module temperature rating is industrial, not automotive.** The Verdin
  iMX95 IT variants are −40 °C to +85 °C, unlike the AEC-Q100 parts used
  across the rest of this family. Acceptable for a cabin/dash mount but a
  real deviation from the family's engine-bay-rated standard, and worth a
  deliberate decision rather than an accident.
- **Pass-FET SOA and TMR sizing.** The LM74930-Q1's overvoltage clamp is
  timed rather than indefinite, so the TMR capacitor must be sized to
  ride out a 60 V / 200 ms load dump, and the pass MOSFET must survive
  dissipating that event inside its safe operating area. Neither number
  is chosen yet, and SOA is the one most likely to drive the FET choice.
- **Watch the LM74930-Q1 thermal pad.** Its datasheet says the exposed
  pad (RTN) must be left **floating — explicitly "Do Not connect to GND
  plane"**. That is the opposite of the near-universal VQFN convention,
  so both the footprint and the PCB generator need a deliberate exception
  or the part will be destroyed by a routine ground stitch.
- **Verdin power consumption is still unknown.** The module datasheet
  gives no current figure, deferring to the Verdin Family Specification,
  which has not been pulled. The 5 V rail is provisionally sized on the
  LM61460-Q1's 6 A rather than on a real budget.
- **Unit E may need splitting.** At 158 pins it is ~200 mm per side,
  which fits an A3 sheet only marginally. Splitting it into two units of
  ~79 is the likely fix, but the real constraint will not be known until
  the symbol generator exists.
- Verdin iMX95 datasheet is marked *Preliminary — Subject to change*;
  the pinout should be re-extracted against a final revision before fab.
- Carrier must follow the Verdin Carrier Board Design Guide (Toradex doc
  108140), which has not yet been reviewed.
- Toradex publishes free reference carrier schematics with symbols and
  IPC-7351 footprints — not yet pulled in, but likely the right source for
  the X1 socket footprint rather than drawing one.

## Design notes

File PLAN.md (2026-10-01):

# Fascia plan

Where the board stands, what is left, and what each remaining step is
blocked on. Last updated 2026-09-30.

Legend: [x] done and verified, [~] done but not fully verified or not
finished, [ ] not started, [!] blocked on something outside this repo.

## 1. Where we are

| Stage | State |
| --- | --- |
| Schematic | [~] Generated, ERC has 10 findings; 6 of them wait on the iFan datasheet |
| Footprints | [~] LM61460-Q1 generated from datasheet vector art; connectors are still provisional 2.54 mm headers |
| Placement | [x] 118 parts, 148 x 71 mm, schematic parity 0 |
| Routing | [~] 3 of ~450 connections open (see section 2) |
| Differential pairs | [ ] Routed but not tuned; worst skew is 20 mm |
| BOM | [ ] None yet |
| Fab outputs | [ ] None yet |
| Project webpage | [~] Exists, but still says "schematic only, no PCB yet" |

## 2. Routing: finish the last 3 connections

The board is routed except for `AOUT_RL_N` (U9.28 to J5.6), `U9_ADR1_TIE`
(R36.1 to U9.44) and `LVDS_A_Y0N` (J4.2 to U5.47). FreeRouting cannot
close them: 150 passes oscillated between 3 and 4 unrouted, and a second
run reported 1 unrouted while `kicad-cli` DRC found 8. A stochastic restart
is a coin flip, so `finish_routes.py` routes them deterministically with an
A* search through the real copper and then lets DRC judge.

- [x] `route_board.py` ported from the siblings; streams FreeRouting output
      to `Fascia-route.log` so a slow run is visible
- [x] Placement fixed so routing is tractable: bridge and socket placed
      together, passives pulled next to their IC, spacing 1.3 to 2.0 mm
      (22 unrouted at 12 passes became 4)
- [~] `finish_routes.py` written and working, but it does not close the gap
      yet. Findings:
  - All three open pads are **sealed in**: fine-pitch QFP pads whose
    neighbours' fan-out tracks leave a one-cell corridor that ends at a
    wall (`U9.28` can reach only its own 1.55 mm length). That is why
    FreeRouting stalled on exactly these.
  - With rip-up enabled the script does route all three (41, 31 and 43 mm
    of track), but ripping up what walled them in opens 17 other
    connections, and the next round re-routing those rips up more:
    20 open after round 1, 20 open after round 3, plus 25-45 real
    clearance violations from the 0.05 mm grid. Net result is worse than
    the 3-open board, so the script **restores the original board when DRC
    says it is not better**. Checked: it does.
  - Tried the next idea: **negotiated (soft-obstacle) routing**, where the
    search crosses other nets' tracks at a cost and only the copper the
    path actually crosses is ripped; pads stay hard. It did not converge
    either: open connections went 3 -> 17 -> 16 -> 21 over four rounds,
    with 59 real violations at the end, and the safety net restored the
    original board. Ripping what a path crosses still opens the nets it
    cuts, and re-laying those crosses something else.
  - My reading, which the runs suggest but do not prove: this is more a
    congestion problem than a router-quality one. Ten AOUT
    pins (five differential pairs) leave `U9`'s left edge at 0.5 mm pitch
    beside GND, the mic and I2S fan-out, and the codec's other nets, and
    the same is true at `U5`'s LVDS side. There is not room for all of them
    to escape, so any one connection that is forced through displaces
    another. More router will not fix that; more room or a different
    arrangement will.
- [ ] DRC-verified result: 0 unconnected items, no new clearance violations

Acceptance: `python run_drc.py` reports schematic parity 0, 0 unconnected
items, and nothing outside the two expected categories.

Ways forward, cheapest first:

1. Hand-route the last three in KiCad. Nudging a few fan-out tracks near
   `U9` and `U5` is quick by hand, and a person can see which neighbour is
   the cheapest to move.
2. Give `U9` and `U5` more room: a larger `CLEAR` just around those two
   parts (or a keep-out ring) in `build_pcb.py`, then re-run
   `route_board.py`. Spacing 1.3 to 2.0 mm already took 12-pass routing from
   22 unrouted to 11, so this is the lever that has worked before.
3. Add layers. Two more inner layers give the audio and LVDS escapes
   somewhere to go, at a fab cost.

## 3. Signal integrity before this is a real board

FreeRouting does not length-match, and the DSI lanes run at about 925 Mbps,
so this is a real gap and not a cosmetic one. `route_board.py` prints the
intra-pair skew; the committed board reads:

| Pair | Skew |
| --- | --- |
| `LVDS_A_Y1` | 20 mm |
| `DSI_D2` | 15 mm |
| `LVDS_B_Y0` | 10 mm |
| `DSI_D3` | 9 mm |
| `LVDS_B_CLK` | 8 mm |

- [ ] Decide the skew budget for DSI (per lane and lane-to-clock) and LVDS
      from the SN65DSI85-Q1 datasheet, not from habit
- [ ] Meander the short leg of each over-budget pair, or re-route the pair
      together
- [ ] Set up a controlled-impedance stackup: 90 to 100 ohm differential on
      DSI and LVDS, and confirm the fab can hit it
- [ ] Re-run the skew report and keep the numbers in the README

## 4. Blocked on the iFan panel datasheet [!]

Requested 2026-08-16, not received. Until it arrives:

- [!] Backlight boost converter: string voltage and current are unpublished,
      so the converter cannot be sized
- [!] Panel connector: the real part is a 60-pin FFC with an unknown
      pinout; the board carries a provisional 22-pin header
- [!] Touch link: USB or I2C depends on the controller IC
- [!] Bezel and mechanical
- [!] LVDS bit-mapping convention (VESA vs JEIDA)

Action: follow up with iFan. The list of questions is in README, "Known
open items". Six of the ten ERC findings clear when this lands.

## 5. Decisions that are still open

- [ ] USB-C receptacle: needs a real 24-pad footprint and a matching
      24-pin symbol; currently a placeholder header
- [ ] `DSI_IRQ` wants a spare 1.8 V GPIO; `IGN_SENSE` wants a module ADC
- [ ] TVS sizing, pass-FET SOA, and TMR capacitor for a 60 V / 200 ms load
      dump (the LM74930-Q1 clamp is timed, not indefinite)
- [ ] Verdin current draw is unknown; the 5 V rail is sized on the
      LM61460-Q1's 6 A, not on a real budget
- [ ] Verdin iMX95 IT variants are industrial (-40 to +85 C), not AEC-Q100;
      acceptable for a cabin mount but it should be a recorded decision
- [ ] Confirm DSI timing on a Verdin EVK with the real panel before fab.
      It closes on paper with about 7% headroom and needs reduced-blanking
      timing; the fallback is 1920 x 1080
- [ ] LM74930-Q1 exposed pad must stay floating, which is the opposite of
      the usual stitch-to-GND rule; confirm the footprint and generator
      both honour it before any fab output

## 6. Path to fab

1. [~] Finish routing (section 2)
2. [ ] Tune the differential pairs (section 3)
3. [!] Resolve the panel-dependent items (section 4)
4. [ ] Replace provisional connectors with real parts and footprints
5. [ ] Clear the remaining silkscreen-over-mask finding
6. [ ] Generate the BOM, following `cluster-pcb/display/build_bom.py`
7. [ ] Purchasing pass: MPNs, stock, lead time (the Verdin SoM and the
       panel first)
8. [ ] Generate fab outputs and run a fab-side DFM check
9. [ ] Second review of the whole schematic against the datasheets

## 7. Software (separate from the board)

- [x] First Android Automotive build succeeded 2026-08-18; Verdin is a
      supported target in `automotive-16.0.0_1.3.0`
- [ ] The M33 System Manager is still built with the EVK board config and
      needs the Verdin one
- [ ] Bring-up on a real carrier: DSI bridge configuration, codec, USB-C
      host mode, CAN to `ecu-pcb`

## 8. Housekeeping

- [x] README "Known open items" no longer claims there is no PCB
- [ ] Project webpage status text (`car-parts-shop`, `projects/fascia`)
      still says schematic only
- [ ] Update the memory note once routing closes

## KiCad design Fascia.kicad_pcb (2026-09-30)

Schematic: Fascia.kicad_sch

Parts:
C1: 100uF; C_0603_1608Metric
C2: 100n CVS; C_0603_1608Metric
C3: 100n CCAP; C_0603_1608Metric
C4: open CT; C_0603_1608Metric
C5, C9, C22: 10u in; C_0603_1608Metric
C6: 1u VCC; C_0603_1608Metric
C7: 100n boot; C_0603_1608Metric
C8: 44u out; C_0603_1608Metric
C10, C23: 10u out; C_0603_1608Metric
C11: 100n VCC; C_0603_1608Metric
C12: 100n VIO; C_0603_1608Metric
C13: 4n7 split; C_0603_1608Metric
C14: 1u VCORE; C_0603_1608Metric
C15: 10u 1V8; C_0603_1608Metric
C16, C17, C18, C19, C20, C21: 100n 1V8; C_0603_1608Metric
C24: 100n U7A; C_0603_1608Metric
C25: 100n U7B; C_0603_1608Metric
C26: 100n U8A; C_0603_1608Metric
C27: 100n U8B; C_0603_1608Metric
C28, C29, C30: 10u decouple; C_0603_1608Metric
C31, C32, C33, C34: 100n codec; C_0603_1608Metric
C35: 100n RST; C_0603_1608Metric
C36: 1u couple; C_0603_1608Metric
C37: 100n IN; C_0603_1608Metric
C38: 150u VBUS; C_0603_1608Metric
C39: 100n; C_0603_1608Metric
D1: TVS 33V; D_SMB
D2: ESD DP; D_SMB
D3: ESD DN; D_SMB
D4: ESD VBUS; D_SMB
F1: 5A; Fuse_Bourns_MF-RG300
J1: Verdin iMX95; SODIMM-260_DDR4_H4.0-5.2_OrientationStd_Socket
J2: Power in; PinHeader_1x03_P2.54mm_Vertical
J3: CAN to ECU; PinHeader_1x03_P2.54mm_Vertical
J4: Panel LVDS (provisional); PinHeader_1x22_P2.54mm_Vertical
J5: Pre-outs to amp; PinHeader_1x11_P2.54mm_Vertical
J6: Mic; PinHeader_1x03_P2.54mm_Vertical
J7: USB-C CarPlay; PinHeader_1x09_P2.54mm_Vertical
J8: JTAG debug; PinHeader_1x08_P2.54mm_Vertical
J9: Buttons; PinHeader_1x04_P2.54mm_Vertical
J10: RTC coin cell; BatteryHolder_Keystone_1058_1x2032
L1: 2.2u; L_1210_3225Metric
Q1: NFET diode; SOT-23
Q2: NFET pass; SOT-23
Q3, Q4: NFET i2c xlat; SOT-23
R1: 2m sense; R_0603_1608Metric
R2: 50R; R_0603_1608Metric
R3: RILIM; R_0603_1608Metric
R4: 5k RMON; R_0603_1608Metric
R5: OV top; R_0603_1608Metric
R6: OV bot; R_0603_1608Metric
R7: UV top; R_0603_1608Metric
R8: UV bot; R_0603_1608Metric
R9: RBOOT; R_0603_1608Metric
R10, R17, R23: FB top; R_0603_1608Metric
R11, R18, R24: FB bot; R_0603_1608Metric
R12: RT; R_0603_1608Metric
R13: EN top; R_0603_1608Metric
R14: EN bot; R_0603_1608Metric
R15, R38: 100k FLT pu; R_0603_1608Metric
R16: 100k PG pu; R_0603_1608Metric
R19, R20: 60R term; R_0603_1608Metric
R21: 10k STB pd; R_0603_1608Metric
R22: 10k REFCLK; R_0603_1608Metric
R25, R26, R27, R28: 2k2 pullup; R_0603_1608Metric
R29: 100k RST; R_0603_1608Metric
R30: 2k2 mic bias; R_0603_1608Metric
R31, R32: 10k bias; R_0603_1608Metric
R33, R34, R35, R36: 10k tie-off; R_0603_1608Metric
R37: 36k ILIM; R_0603_1608Metric
R39: 10k Rp CC1; R_0603_1608Metric
R40: 10k Rp CC2; R_0603_1608Metric
R41: 0R ID; R_0603_1608Metric
R42: 100k Vsense; R_0603_1608Metric
R43: 56k Vsense; R_0603_1608Metric
R44, R45, R46, R47: 10k pullup; R_0603_1608Metric
R48: 10k JTAG Vref; R_0603_1608Metric
R49: 47k min; R_0603_1608Metric
U1: LM74930-Q1; Texas_RGE0024H_VQFN-24-1EP_4x4mm_P0.5mm_EP2.7x2.7mm
U2: LM61460-Q1; TI_RJR0014A_VQFN-HR-14_4x3.5mm
U3: TLV767-Q1; Texas_DRB0008A
U4: TCAN1044V-Q1; SOIC-8_3.9x4.9mm_P1.27mm
U5: SN65DSI85-Q1; Texas_TQFP-64-1EP_10x10mm_P0.5mm_EP8x8mm_Mask4.44x4.44mm
U6: TLV767-Q1 3V3; Texas_DRB0008A
U7, U8: SN74AXC4T245-Q1; TSSOP-16_4.4x5mm_P0.65mm
U9: PCM3168A-Q1; Texas_TQFP-64-1EP_10x10mm_P0.5mm_EP8x8mm_Mask4.44x4.44mm
U10: TPS2557-Q1; Texas_DRB0008A

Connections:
+1V8: C10.1, C12.1, C15.1, C16.1, C17.1, C18.1, C19.1, C20.1, C21.1, C24.1, C26.1, Q3.1 (G), Q4.1 (G), R17.1, R25.2, R26.2, R38.2, R44.2, R45.2, R46.2, R47.2, R48.2, U3.1 (OUT), U4.5 (VIO), U5.3 (VCC1), U5.14 (VCC2), U5.18 (VCC3), U5.32 (VCC4), U5.35 (VCC5), U5.40 (VCC6), U5.43 (VCC7), U5.48 (VCC8), U5.49 (VCC9), U5.55 (VCC10), U5.58 (VCC11), U5.63 (VCC12), U7.1 (VCCA), U7.2 (1DIR), U7.3 (2DIR), U8.1 (VCCA), U8.3 (2DIR)
+3V3: C23.1, C25.1, C27.1, C33.1, C34.1, R23.1, R27.2, R28.2, R29.1, U6.1 (OUT), U7.16 (VCCB), U8.16 (VCCB), U9.12 (VDD2), U9.46 (VDD1)
+5V: C8.1, C9.1, C11.1, C22.1, C31.1, C32.1, C37.1, J1.251 (VCC), J1.253 (VCC), J1.255 (VCC), J1.257 (VCC), J1.259 (VCC), L1.2, R10.1, R15.2, R16.2, R30.1, R39.2, R40.2, U2.1 (BIAS), U3.8 (IN), U4.3 (VCC), U6.8 (IN), U9.3 (VCCAD2), U9.14 (VCCDA1), U9.34 (VCCDA2), U9.49 (VCCAD1), U10.2 (IN1), U10.3 (IN2)
+12V_PROT: C5.1, Q1.2 (D), R13.1, U1.18 (ISCP), U1.24 (C), U2.8 (VIN1), U2.12 (VIN2)
AOUT_FL_N: J5.2 (FL_N), U9.32 (VOUT1N)
AOUT_FL_P: J5.1 (FL_P), U9.31 (VOUT1P)
AOUT_FR_N: J5.4 (FR_N), U9.30 (VOUT2N)
AOUT_FR_P: J5.3 (FR_P), U9.29 (VOUT2P)
AOUT_RL_N: J5.6 (RL_N), U9.28 (VOUT3N)
AOUT_RL_P: J5.5 (RL_P), U9.27 (VOUT3P)
AOUT_RR_N: J5.8 (RR_N), U9.26 (VOUT4N)
AOUT_RR_P: J5.7 (RR_P), U9.25 (VOUT4P)
AOUT_SUB_N: J5.10 (SUB_N), U9.24 (VOUT5N)
AOUT_SUB_P: J5.9 (SUB_P), U9.23 (VOUT5P)
BOOT_C: C7.1, R9.2, U2.14 (CBOOT)
BOOT_R: R9.1, U2.13 (RBOOT)
CAN1_H: J3.1 (CANH), R19.1, U4.7 (CANH)
CAN1_L: J3.2 (CANL), R20.2, U4.6 (CANL)
CAN1_RXD: J1.22 (CAN_1_RX), U4.4 (RXD)
CAN1_SPLIT: C13.1, R19.2, R20.1
CAN1_STB: R21.1, U4.8 (STB)
CAN1_TXD: J1.20 (CAN_1_TX), U4.1 (TXD)
CAP_CP: C3.1, U1.23 (CAP)
CODEC_DOUT_1V8: J1.36 (I2S_1_D_IN), U8.4 (1A1)
CODEC_DOUT_3V3: U8.13 (1B1), U9.8 (DOUT1)
CODEC_RST: C35.1, R29.2, U9.4 (RST)
CODEC_SCL_3V3: Q4.2 (D), R28.1, U9.42 (SCL)
CODEC_SDA_3V3: Q3.2 (D), R27.1, U9.43 (SDA)
COMMON: Q1.3 (S), Q2.3 (S), U1.2 (A), U1.15 (OUT)
CS_PLUS: R2.2, U1.20 (CS+)
DGATE: Q1.1 (G), U1.1 (DGATE)
DSI_BRIDGE_EN: J1.17 (GPIO_9_DSI), U5.2 (EN)
DSI_CLK_N: J1.35 (DSI_1_CLK_N), U5.25 (DACN)
DSI_CLK_P: J1.37 (DSI_1_CLK_P), U5.24 (DACP)
DSI_D0_N: J1.47 (DSI_1_D0_N), U5.20 (DA0N)
DSI_D0_P: J1.49 (DSI_1_D0_P), U5.19 (DA0P)
DSI_D1_N: J1.41 (DSI_1_D1_N), U5.22 (DA1N)
DSI_D1_P: J1.43 (DSI_1_D1_P), U5.21 (DA1P)
DSI_D2_N: J1.29 (DSI_1_D2_N), U5.28 (DA2N)
DSI_D2_P: J1.31 (DSI_1_D2_P), U5.27 (DA2P)
DSI_D3_N: J1.23 (DSI_1_D3_N), U5.30 (DA3N)
DSI_D3_P: J1.25 (DSI_1_D3_P), U5.29 (DA3P)
DSI_I2C_SCL: J1.55 (I2C_2_DSI_SCL), U5.15 (SCL)
DSI_I2C_SDA: J1.53 (I2C_2_DSI_SDA), U5.16 (SDA)
EN_5V: R13.2, R14.1, U2.7 (EN/SYNC)
FB_1V8: R17.2, R18.1, U3.3 (FB)
FB_3V3: R23.2, R24.1, U6.3 (FB)
FB_5V: R10.2, R11.1, U2.4 (FB)
GND: C1.2, C2.2, C4.2, C5.2, C6.2, C8.2, C9.2, C10.2, C11.2, C12.2, C13.2, C14.2, C15.2, C16.2, C17.2, C18.2, C19.2, C20.2, C21.2, C22.2, C23.2, C24.2, C25.2, C26.2, C27.2, C28.2, C29.2, C30.2, C31.2, C32.2, C33.2, C34.2, C35.2, C37.2, C38.2, C39.2, D1.2, D2.2, D3.2, D4.2, J1.10 (GND), J1.11 (GND), J1.18 (GND), J1.27 (GND), J1.28 (GND), J1.33 (GND), J1.39 (GND), J1.40 (GND), J1.45 (GND), J1.50 (GND), J1.51 (GND), J1.65 (GND), J1.68 (GND), J1.71 (GND), J1.77 (GND), J1.83 (GND), J1.86 (GND), J1.89 (GND), J1.97 (GND), J1.98 (GND), J1.103 (GND), J1.109 (GND), J1.110 (GND), J1.115 (GND), J1.121 (GND), J1.122 (GND), J1.127 (GND), J1.134 (GND), J1.145 (GND), J1.146 (GND), J1.158 (GND), J1.167 (GND), J1.170 (GND), J1.173 (GND), J1.179 (GND), J1.182 (GND), J1.194 (GND), J1.195 (GND), J1.204 (GND), J1.209 (GND), J1.223 (GND), J1.224 (GND), J1.229 (GND), J1.230 (GND), J1.236 (GND), J1.242 (GND), J1.243 (GND), J2.2 (GND), J3.3 (GND), J4.21 (GND1), J4.22 (GND2), J5.11 (GND), J6.3 (GND), J7.8 (GND), J7.9 (SHIELD), J8.8 (GND), J9.4 (GND), J10.2 (GND), R3.2, R4.2, R6.2, R8.2, R11.2, R12.2, R14.2, R18.2, R21.2, R22.2, R24.2, R33.2, R34.2, R35.2, R36.2, R37.2, R41.2, R43.2, U1.13 (GND), U2.3 (AGND), U2.9 (PGND1), U2.11 (PGND2), U3.4 (GND), U3.6 (GND2), U3.9 (EP), U4.2 (GND), U5.23 (GND1), U5.26 (GND2), U5.52 (GND3), U5.64 (ADDR), U5.65 (EP), U6.4 (GND), U6.6 (GND2), U6.9 (EP), U7.8 (GND1), U7.9 (GND2), U7.14 (2OE), U7.15 (1OE), U8.2 (1DIR), U8.8 (GND1), U8.9 (GND2), U8.14 (2OE), U8.15 (1OE), U9.2 (AGNDAD2), U9.11 (DGND2), U9.16 (AGNDDA1), U9.33 (AGNDDA2), U9.45 (ADR0), U9.47 (DGND1), U9.48 (MODE), U9.50 (AGNDAD1), U9.60 (VREFAD2), U9.65 (EP), U10.1 (GND), U10.9 (EP)
HGATE: Q2.1 (G), U1.14 (HGATE)
I2C1_SCL_1V8: J1.14 (I2C_1_SCL), Q4.3 (S), R26.1
I2C1_SDA_1V8: J1.12 (I2C_1_SDA), Q3.3 (S), R25.1
I2S_BCK_1V8: J1.30 (I2S_1_BCLK), U7.4 (1A1)
I2S_BCK_3V3: U7.13 (1B1), U9.7 (BCKAD), U9.36 (BCKDA)
I2S_DIN_1V8: J1.34 (I2S_1_D_OUT), U7.6 (2A1)
I2S_DIN_3V3: U7.11 (2B1), U9.37 (DIN1)
I2S_LRCK_1V8: J1.32 (I2S_1_SYNC), U7.5 (1A2)
I2S_LRCK_3V3: U7.12 (1B2), U9.6 (LRCKAD), U9.35 (LRCKDA)
I2S_SCKI_1V8: J1.38 (I2S_1_MCLK), U7.7 (2A2)
I2S_SCKI_3V3: U7.10 (2B2), U9.41 (SCKI)
ILIM: R3.1, U1.11 (ILIM)
IMON: R4.1, U1.10 (IMON)
JTAG_TCK: J1.9 (JTAG_1_TCK), J8.3 (TCK)
JTAG_TDI: J1.1 (JTAG_1_TDI), J8.5 (TDI)
JTAG_TDO: J1.5 (JTAG_1_TDO), J8.4 (TDO)
JTAG_TMS: J1.13 (JTAG_1_TMS), J8.2 (TMS)
JTAG_TRST: J1.3 (JTAG_1_TRST#), J8.6 (TRST)
JTAG_VREF: J1.7 (JTAG_1_VREF), J8.1 (VREF), R48.1
LVDS_A_CLKN: J4.10 (A_CLKN), U5.39 (A_CLKN)
LVDS_A_CLKP: J4.9 (A_CLKP), U5.38 (A_CLKP)
LVDS_A_Y0N: J4.2 (A_Y0N), U5.47 (A_Y0N)
LVDS_A_Y0P: J4.1 (A_Y0P), U5.46 (A_Y0P)
LVDS_A_Y1N: J4.4 (A_Y1N), U5.45 (A_Y1N)
LVDS_A_Y1P: J4.3 (A_Y1P), U5.44 (A_Y1P)
LVDS_A_Y2N: J4.6 (A_Y2N), U5.42 (A_Y2N)
LVDS_A_Y2P: J4.5 (A_Y2P), U5.41 (A_Y2P)
LVDS_A_Y3N: J4.8 (A_Y3N), U5.37 (A_Y3N)
LVDS_A_Y3P: J4.7 (A_Y3P), U5.36 (A_Y3P)
LVDS_B_CLKN: J4.20 (B_CLKN), U5.54 (B_CLKN)
LVDS_B_CLKP: J4.19 (B_CLKP), U5.53 (B_CLKP)
LVDS_B_Y0N: J4.12 (B_Y0N), U5.62 (B_Y0N)
LVDS_B_Y0P: J4.11 (B_Y0P), U5.61 (B_Y0P)
LVDS_B_Y1N: J4.14 (B_Y1N), U5.60 (B_Y1N)
LVDS_B_Y1P: J4.13 (B_Y1P), U5.59 (B_Y1P)
LVDS_B_Y2N: J4.16 (B_Y2N), U5.57 (B_Y2N)
LVDS_B_Y2P: J4.15 (B_Y2P), U5.56 (B_Y2P)
LVDS_B_Y3N: J4.18 (B_Y3N), U5.51 (B_Y3N)
LVDS_B_Y3P: J4.17 (B_Y3P), U5.50 (B_Y3P)
MIC_BIAS_P: C36.1, J6.1 (MIC_P), R30.2
MIC_IN_N: J6.2 (MIC_N), R32.2, U9.51 (VIN1N)
MIC_IN_P: C36.2, R31.2, U9.52 (VIN1P)
OV_DIV: R5.2, R6.1, U1.5 (OV), U1.16 (OVCLAMP)
PG_5V: R16.1, U2.5 (PGOOD)
PWR_BTN: J1.248 (CTRL_PWR_BTN_MICO#), J9.1 (PWR_BTN), R44.1
PWR_EN_MOCI: J1.254 (CTRL_PWR_EN_MOCI), U3.5 (EN), U6.5 (EN)
PWR_FLT: R15.1, U1.12 (FLT)
RECOVERY: J1.246 (CTRL_RECOVERY_MICO#), J9.2 (RECOVERY), R45.1
REFCLK_GND: R22.1, U5.17 (REFCLK)
RESET_MICO: J1.260 (CTRL_RESET_MICO#), J8.7 (RESET), J9.3 (RESET), R46.1
RESET_MOCI: J1.258 (CTRL_RESET_MOCI#), R47.1
RT_5V: R12.1, U2.6 (RT)
SENSE_OUT: Q2.2 (D), R1.2, U1.19 (CS-)
SW_5V: C7.2, L1.1, U2.10 (SW)
SW_SENSE: R5.1, R7.1, U1.3 (SW)
TMR: C4.1, U1.9 (TMR)
U8_1B2_TIE: R33.1, U8.12 (1B2)
U8_2A1_TIE: R34.1, U8.6 (2A1)
U8_2A2_TIE: R35.1, U8.7 (2A2)
U9_ADR1_TIE: R36.1, U9.44 (ADR1)
USB1_DN: D3.1, J1.163 (USB_1_D_N), J7.3 (DN)
USB1_DP: D2.1, J1.165 (USB_1_D_P), J7.2 (DP)
USB1_EN: J1.155 (USB_1_EN), U10.4 (EN)
USB1_ID: J1.161 (USB_1_ID), R41.1
USB1_OC: J1.157 (USB_1_OC#), R38.1, U10.8 (FAULT)
USB1_VBUS_SENSE: J1.159 (USB_1_VBUS), R42.2, R43.1
USB_CC1: J7.4 (CC1), R39.1
USB_CC2: J7.5 (CC2), R40.1
USB_ILIM: R37.1, U10.5 (ILIM)
USB_VBUS: C38.1, D4.1, J7.1 (VBUS), R42.1, U10.6 (OUT1), U10.7 (OUT2)
UVLO_DIV: R7.2, R8.1, U1.4 (UVLO)
VBACKUP: C39.1, J1.249 (VCC_BACKUP), R49.2
VBACKUP_CELL: J10.1 (VBAT), R49.1
VBAT_F: C1.1, C2.1, C3.2, D1.1, F1.2, R1.1, R2.1, U1.6 (EN), U1.7 (MODE), U1.22 (VS)
VBAT_IN: F1.1, J2.1 (VBAT)
VCC_LDO: C6.1, U2.2 (VCC)
VCOMAD: C28.1, R31.1, R32.1, U9.1 (VCOMAD)
VCOMDA: C29.1, U9.15 (VCOMDA)
VCORE_1V1: C14.1, U5.31 (VCORE)
VREFAD1: C30.1, U9.59 (VREFAD1)

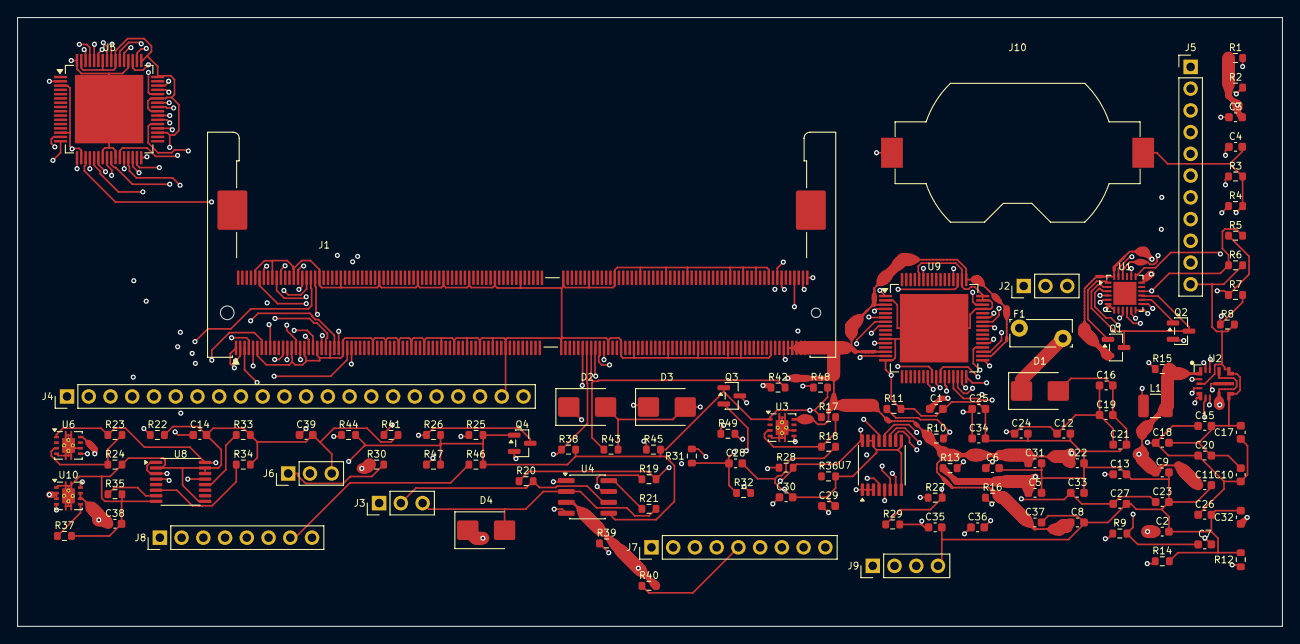
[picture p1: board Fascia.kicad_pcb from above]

Board: 6 copper layers, 147.8 x 71.1 mm, 118 parts (0 on the bottom side), 129 nets.

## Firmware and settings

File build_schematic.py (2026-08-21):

#!/usr/bin/env python3
"""
build_schematic.py - generates Fascia.kicad_sch / Fascia.kicad_sym.

Same script-driven discipline as the sibling manifold-pcb / ecu-pcb /
thermo-pcb projects: this script is the source of truth. Never hand-edit
the generated .kicad_sch or .kicad_sym - change this file and re-run.

Current stage: the Verdin iMX95 X1 module connector, the 12 V automotive
front end, the 5 V buck, the 1.8 V LDO, the CAN FD link, and the
SN65DSI85-Q1 DSI-to-LVDS bridge with its panel connector. The audio
codec, the USB-C port and the backlight driver are not here yet, so this
is deliberately an incomplete schematic - see README.md's "Status".

What IS final at this stage:
  - all 260 X1 pins exist, banked into 6 units by verdin_x1.py
  - every GND pin is tied to ground, every VCC pin to the +5V rail
  - all 158 pins this board does not use carry real NoConnect items
  - LM74930-Q1, LM61460-Q1, TLV767-Q1, TCAN1044V-Q1 and SN65DSI85-Q1 are
    all fully wired, every pin netted or NoConnected
  - the module's CAN and full DSI link now reach their destinations

`kicad-cli sch erc` reports 37 violations, all expected: 35 X1 pins
awaiting the codec, USB-C and backlight blocks, plus IGN_SENSE and
DSI_IRQ, which have no destination yet.
"""
import json
import os
import subprocess
import sys
import uuid as uuid_lib

from kiutils.schematic import Schematic
from kiutils.symbol import Symbol, SymbolPin, SymbolLib
from kiutils.items.common import (Position, Property, Effects, Font, Stroke,
                                  Justify)
from kiutils.items.syitems import SyRect, SyPolyLine
from kiutils.items.schitems import (SchematicSymbol, Connection, LocalLabel,
                                    NoConnect, SymbolProjectPath,
                                    SymbolProjectInstance)

HERE = os.path.dirname(os.path.abspath(__file__))
sys.path.insert(0, HERE)

from verdin_pinout import X1_PINS                      # noqa: E402
import verdin_x1                                       # noqa: E402
import parts                                           # noqa: E402

LIB = "Fascia"
OUT_SCH = os.path.join(HERE, "Fascia.kicad_sch")
OUT_SYM = os.path.join(HERE, "Fascia.kicad_sym")
OUT_TABLE = os.path.join(HERE, "sym-lib-table")
OUT_PRO = os.path.join(HERE, "Fascia.kicad_pro")

# A0. The 260-pin connector alone fills an A2; adding the power tree,
# bridge, CAN and audio blocks filled A1 to the point where two sections
# collided and silently merged a net. Each block now gets its own band
# with real separation between them. This project's KiCad notes record that content
# running off a fixed sheet is invisible in the editor and only shows on
# a real fixed-size export, so main() checks every placement against the
# sheet bounds.
PAPER = "A0"
SHEET_W, SHEET_H = 1189.0, 841.0

GRID = 1.27
PITCH = 2.54          # pin-to-pin spacing down a symbol side
LEAD = 5.08           # pin lead length
UNIT_W = 63.5         # body width; wide enough for names like CTRL_RECOVERY_MICO#
STUB = 5.08           # wire length from a power pin out to its power symbol

# Verdin iMX95 pins that are genuinely supplies, not signals. Everything
# else on the connector is typed passive: this is a board-to-board
# connector, so ERC has no business inferring signal direction from it.
POWER_IN = {"GND", "VCC"}

# X1 signal pins that now have somewhere to go. Anything not listed is
# still awaiting its block and stays deliberately unconnected, which ERC
# reports and main() checks against the expected set.
X1_NETS = {
    "CAN_1_TX": "CAN1_TXD",     # module drives the transceiver's TXD
    "CAN_1_RX": "CAN1_RXD",     # transceiver's RXD drives the module
    # MIPI DSI into the SN65DSI85-Q1. These are the pairs that stay ON
    # the carrier - the long run to the panel is LVDS out of the bridge.
    "DSI_1_D0_P": "DSI_D0_P", "DSI_1_D0_N": "DSI_D0_N",
    "DSI_1_D1_P": "DSI_D1_P", "DSI_1_D1_N": "DSI_D1_N",
    "DSI_1_D2_P": "DSI_D2_P", "DSI_1_D2_N": "DSI_D2_N",
    "DSI_1_D3_P": "DSI_D3_P", "DSI_1_D3_N": "DSI_D3_N",
    "DSI_1_CLK_P": "DSI_CLK_P", "DSI_1_CLK_N": "DSI_CLK_N",
    "I2C_2_DSI_SDA": "DSI_I2C_SDA", "I2C_2_DSI_SCL": "DSI_I2C_SCL",
    "GPIO_9_DSI": "DSI_BRIDGE_EN",
    # Audio. Every one of these crosses a voltage domain on its way to the
    # codec - see build_audio() for why that is not optional.
    "I2S_1_BCLK":  "I2S_BCK_1V8",
    "I2S_1_SYNC":  "I2S_LRCK_1V8",
    "I2S_1_D_OUT": "I2S_DIN_1V8",     # module out -> codec DIN
    "I2S_1_D_IN":  "CODEC_DOUT_1V8",  # codec DOUT -> module in
    "I2S_1_MCLK":  "I2S_SCKI_1V8",    # master clock -> codec SCKI
    "I2C_1_SDA":   "I2C1_SDA_1V8",
    "I2C_1_SCL":   "I2C1_SCL_1V8",
    # USB-C for wired CarPlay / Android Auto. EN and OC# need no level
    # shifting: the switch's VIH is 1.1 V and its FAULT is pulled to the
    # 1.8 V rail, so both sit inside the module's rating.
    "USB_1_D_N":  "USB1_DN",
    "USB_1_D_P":  "USB1_DP",
    "USB_1_EN":   "USB1_EN",
    "USB_1_OC#":  "USB1_OC",
    "USB_1_VBUS": "USB1_VBUS_SENSE",
    "USB_1_ID":   "USB1_ID",
    # Control and sequencing.
    "CTRL_PWR_EN_MOCI":  "PWR_EN_MOCI",
    "CTRL_RESET_MOCI#":  "RESET_MOCI",
    "CTRL_RESET_MICO#":  "RESET_MICO",
    "CTRL_PWR_BTN_MICO#": "PWR_BTN",
    "CTRL_RECOVERY_MICO#": "RECOVERY",
    "JTAG_1_TCK":   "JTAG_TCK",
    "JTAG_1_TMS":   "JTAG_TMS",
    "JTAG_1_TDI":   "JTAG_TDI",
    "JTAG_1_TDO":   "JTAG_TDO",
    "JTAG_1_TRST#": "JTAG_TRST",
    "JTAG_1_VREF":  "JTAG_VREF",
    "VCC_BACKUP":   "VBACKUP",
}

# X1 pins this board deliberately does not use, outside the unused bank.
# Each one the Verdin datasheet explicitly permits leaving floating, or
# that this design has no use for. They get real NoConnect items, same as
# bank E, rather than being left to show up as ERC noise.
X1_NC = {
    "CTRL_FORCE_OFF_MOCI#",  # datasheet: "can be left floating"
    "CTRL_WAKE1_MICO#",      # "can be left floating if wake is disabled"
    "CTRL_SLEEP_MOCI#",      # no carrier rail is sequenced off in sleep
    "TAMPER0", "TAMPER1",    # SoC tamper detect, unused here
    "PWR_1V8_MOCI",          # the carrier makes its own 1.8 V
    "PMIC_PGOOD",            # module-side power good, not used by us
}


def U():
    return str(uuid_lib.uuid4())


def snap(v):
    """Round onto KiCad's 1.27 mm schematic grid.

    Applied at every placement entry point. This project's KiCad notes
    record that off-grid pin/wire endpoints produce one real
    `endpoint_off_grid` ERC violation each, even when every connection is
    otherwise correct.
    """
    return round(round(v / GRID) * GRID, 2)


# ---------------------------------------------------------------------------
# Symbol library
# ---------------------------------------------------------------------------
lib_symbols = {}          # lib_id -> Symbol
unit_pin_offsets = {}     # (unit_index, pin_number) -> (dx, dy) in symbol space
unit_heights = {}         # unit_index -> drawn body height (mm)


def build_x1_symbol():
    """
    The Verdin iMX95 X1 connector as one multi-unit KiCad symbol.

    Each unit gets its pins split down its two sides, first half on the
    left, second half on the right, in ascending pin order so the drawing
    can be read against the datasheet's own tables.
    """
    lib_id = f"{LIB}:Verdin_iMX95_X1"
    parent = Symbol.create_new(
        id=lib_id, reference="J", value="Verdin iMX95",
        footprint=parts.FOOTPRINTS["Verdin_iMX95_X1"],
        datasheet="https://docs.toradex.com/200007-verdin_imx95_datasheet.pdf")
    parent.pinNames = True
    parent.pinNamesOffset = 0.508
    parent.hidePinNumbers = False

    for idx, (label, desc, entries) in enumerate(verdin_x1.units(), start=1):
        half = -(-len(entries) // 2)          # ceil, so left side takes the extra
        left, right = entries[:half], entries[half:]
        rows = max(len(left), len(right), 1)
        height = rows * PITCH + PITCH
        unit_heights[idx] = height

        child = Symbol(libraryNickname=None, entryName="Verdin_iMX95_X1",
                       unitId=idx, styleId=1)
        child.graphicItems.append(SyRect(
            start=Position(-UNIT_W / 2, -height / 2),
            end=Position(UNIT_W / 2, height / 2),
            stroke=Stroke(width=0.254, type="default")))
        child.graphicItems[-1].fill.type = "background"

        def add_side(items, x_tip, angle):
            n = len(items)
            for i, (pin, name) in enumerate(items):
                # Symbol space is Y-up, so the first entry needs the
                # largest y to land at the TOP of the drawn body.
                py = ((n - 1) * PITCH) / 2 - i * PITCH
                etype = "power_in" if name in POWER_IN else "passive"
                child.pins.append(SymbolPin(
                    electricalType=etype, graphicalStyle="line",
                    position=Position(round(x_tip, 2), round(py, 2), angle),
                    length=LEAD, name=name, number=str(pin)))
                unit_pin_offsets[(idx, pin)] = (round(x_tip, 2), round(py, 2))

        # Pin angle points from the connection tip toward the body, so a
        # left-hand pin is 0 and a right-hand pin is 180.
        add_side(left, -(UNIT_W / 2 + LEAD), 0)
        add_side(right, UNIT_W / 2 + LEAD, 180)
        parent.units.append(child)

    lib_symbols[lib_id] = parent
    return lib_id


def build_power_symbol(net, is_gnd):
    lib_id = f"{LIB}:PWR_{net}"
    sym = Symbol.create_new(id=lib_id, reference="#PWR", value=net)
    sym.isPower = True
    sym.pinNames = True
    sym.pinNamesOffset = 0
    sym.pinNamesHide = True
    sym.hidePinNumbers = True
    sym.properties[0].effects.hide = True
    stroke = Stroke(width=0.254, type="default")
    if is_gnd:
        sym.properties[1].position = Position(0, -4.6, 0)
        shapes = ([(0, 0), (0, -1.27)],
                  [(-1.27, -1.27), (1.27, -1.27)],
                  [(-0.762, -1.905), (0.762, -1.905)],
                  [(-0.254, -2.54), (0.254, -2.54)])
    else:
        sym.properties[1].position = Position(0, 3.9, 0)
        shapes = ([(0, 0), (0, 2.54)], [(-1.016, 2.54), (1.016, 2.54)])
    for pts in shapes:
        sym.graphicItems.append(SyPolyLine(
            points=[Position(a, b) for a, b in pts], stroke=stroke))
    sym.pins = [SymbolPin(electricalType="power_in", graphicalStyle="line",
                          position=Position(0, 0, 90), length=0,
                          name=net, number="1", hide=True)]
    lib_symbols[lib_id] = sym
    return lib_id


def build_pwr_flag(net):
    """
    PWR_FLAG equivalent - asserts that `net` is driven from off-sheet.

    +5V enters this stage with no regulator on the sheet yet, so ERC's
    power_pin_not_driven fires without this. Drawn as an arrow so it does
    not read as another supply if opened in the GUI.
    """
    lib_id = f"{LIB}:PWR_FLAG_{net}"
    sym = Symbol.create_new(id=lib_id, reference="#FLG", value=f"PWR_FLAG {net}")
    sym.isPower = True
    sym.pinNames = True
    sym.pinNamesOffset = 0
    sym.pinNamesHide = True
    sym.hidePinNumbers = True
    sym.properties[0].effects.hide = True
    sym.properties[1].position = Position(0, 3.9, 0)
    stroke = Stroke(width=0.254, type="default")
    for pts in ([(0, 0), (0, 2.54)], [(0, 2.54), (-0.889, 1.651)],
                [(0, 2.54), (0.889, 1.651)]):
        sym.graphicItems.append(SyPolyLine(
            points=[Position(a, b) for a, b in pts], stroke=stroke))
    sym.pins = [SymbolPin(electricalType="power_out", graphicalStyle="line",
                          position=Position(0, 0, 90), length=0,
                          name=net, number="1", hide=True)]
    lib_symbols[lib_id] = sym
    return lib_id


# ---------------------------------------------------------------------------
# Schematic
# ---------------------------------------------------------------------------
sch = Schematic.create_new()
sch.paper.paperSize = PAPER
sch.uuid = U()


def place(lib_id, ref, value, x, y, unit=1, hide_ref=False, body_h=None):
    """
    Place a symbol instance.

    `body_h` is the drawn height of THIS unit. A multi-unit symbol carries
    one set of property positions shared by every unit, so leaving them at
    the library default stacks the reference and value on top of each
    other in the middle of the body. Passing the unit's own height moves
    the reference above it and the value below it. Note the sheet is
    Y-down, so "above" is the smaller y.
    """
    x, y = snap(x), snap(y)
    inst = SchematicSymbol(
        libraryNickname=lib_id.split(":")[0], entryName=lib_id.split(":")[1],
        position=Position(x, y, 0), unit=unit, inBom=True, onBoard=True,
        uuid=U())
    src = lib_symbols[lib_id]
    for i, p in enumerate(src.properties):
        if body_h is not None and i in (0, 1):
            gap = body_h / 2 + 2.54
            pos = Position(x, y - gap if i == 0 else y + gap, 0)
        else:
            pos = Position(x + p.position.X, y - p.position.Y, 0)
        prop = Property(key=p.key, value=(ref if i == 0 else
                                          (value if i == 1 else p.value)),
                        id=i, position=pos,
                        effects=Effects(font=Font(width=1.27, height=1.27)))
        if i == 0 and hide_ref:
            prop.effects.hide = True
        if i >= 2:
            prop.effects.hide = True
        inst.properties.append(prop)
    inst.instances.append(SymbolProjectInstance(
        name=LIB, paths=[SymbolProjectPath(sheetInstancePath=f"/{sch.uuid}",
                                           reference=ref, unit=unit)]))
    sch.schematicSymbols.append(inst)
    return inst


def add_wire(x1, y1, x2, y2):
    sch.graphicalItems.append(Connection(
        type="wire",
        points=[Position(snap(x1), snap(y1)), Position(snap(x2), snap(y2))],
        stroke=Stroke(width=0.0, type="default"), uuid=U()))


def pin_xy(unit, pin, sym_x, sym_y):
    """Sheet coordinates of an X1 pin.

    Symbol space is Y-up while the sheet is Y-down, so the symbol-space
    offset is added in X and SUBTRACTED in Y.
    """
    dx, dy = unit_pin_offsets[(unit, pin)]
    return snap(sym_x + dx), snap(sym_y - dy)


# ---------------------------------------------------------------------------
# Generic parts and the declarative net list
# ---------------------------------------------------------------------------
# Rails get power symbols; everything else gets a stub wire and a local
# label. This project's KiCad notes are explicit that the two mechanisms
# do NOT merge - a label "GND" makes net "/GND" while a power symbol makes
# global "GND" - so each net must pick one and stick to it.
# VBAT_F and +12V_PROT are rails too, not signals: they feed power_in
# pins, so ERC needs them driven. Both arrive through passive parts (a
# fuse, and the ideal-diode FET), so nothing on the sheet "drives" them
# and each needs a PWR_FLAG the same way GND and +5V do.
POWER_NETS = {"GND", "+5V", "+12V_PROT", "+1V8", "+3V3", "VBAT_F"}

# net -> a real (x, y) on that net, for anchoring PWR_FLAGs. This project's
# KiCad notes record that a flag merged only by name, with nothing
# touching it graphically, does not satisfy power_pin_not_driven.
power_net_points = {}

# Rails that a real part actually drives, i.e. something on the net has a
# power_out pin. Those must NOT get a PWR_FLAG: two power outputs on one
# net is a pin_to_pin conflict, and the flag exists precisely to stand in
# for a driver that is not on the sheet.
driven_nets = set()

# Every coordinate a net is terminated at, so two blocks drifting into
# each other can be caught by construction. Keyed on the point, valued
# with (net, owning reference). Covers pin positions AND stub endpoints -
# an earlier version only scanned label positions and therefore missed a
# stub whose endpoint landed on another block's pin.
net_points = {}

generic_pins = {}      # lib_id -> [(num, name, etype), ...]
generic_offsets = {}   # (lib_id, num) -> (dx, dy) symbol space
generic_heights = {}   # lib_id -> body height


def build_generic_symbol(lib_id, ref_prefix, value, pins, footprint=None):
    """A rectangular symbol, pins split first-half left / second-half right."""
    half = -(-len(pins) // 2)
    left, right = pins[:half], pins[half:]
    rows = max(len(left), len(right), 1)
    height = rows * PITCH + PITCH
    longest = max((len(p[1]) for p in pins), default=1)
    # Width must be a multiple of 2.54, NOT merely snapped to 1.27: pins
    # sit at +/-(width/2 + LEAD), so an odd multiple of 1.27 puts every
    # pin half a grid step off. That breaks the assumption place_part's
    # snap() relies on, and shows up not as one tidy error but as a
    # cascade - off-grid pins, then wires whose ends miss those pins,
    # then dangling no-connects and isolated labels on the nets that
    # failed to form. This project's KiCad notes warn to verify the
    # pin-layout math rather than trust a single snap point; this is that
    # precondition being violated.
    width = max(15.24, 2.54 * -(-(longest * 2.0 + 7.62) // 2.54))

    if footprint is None:
        footprint = parts.FOOTPRINTS.get(lib_id.split(":", 1)[1], "")
    sym = Symbol.create_new(id=lib_id, reference=ref_prefix, value=value,
                            footprint=footprint)
    sym.pinNames = True
    sym.pinNamesOffset = 0.508
    sym.graphicItems.append(SyRect(
        start=Position(-width / 2, -height / 2),
        end=Position(width / 2, height / 2),
        stroke=Stroke(width=0.254, type="default")))
    sym.graphicItems[-1].fill.type = "background"

    def side(items, x_tip, angle):
        n = len(items)
        for i, (num, name, etype) in enumerate(items):
            py = ((n - 1) * PITCH) / 2 - i * PITCH
            sym.pins.append(SymbolPin(
                electricalType=etype, graphicalStyle="line",
                position=Position(round(x_tip, 2), round(py, 2), angle),
                length=LEAD, name=name, number=str(num)))
            generic_offsets[(lib_id, num)] = (round(x_tip, 2), round(py, 2))

    side(left, -(width / 2 + LEAD), 0)
    side(right, width / 2 + LEAD, 180)

    lib_symbols[lib_id] = sym
    generic_pins[lib_id] = pins
    generic_heights[lib_id] = height
    return lib_id


# Two-terminal parts all share one shape; three-terminal N-FET its own.
PASSIVE_PINS = [(1, "1", "passive"), (2, "2", "passive")]
NFET_PINS = [(1, "G", "input"), (2, "D", "passive"), (3, "S", "passive")]

rail_syms = {}     # net -> power symbol lib_id


def rail(net):
    """Power symbol for `net`, created on first use."""
    if net not in rail_syms:
        rail_syms[net] = build_power_symbol(net, is_gnd=(net == "GND"))
    return rail_syms[net]


def place_part(lib_id, ref, value, x, y, nets):
    """
    Place a part and terminate every one of its pins.

    `nets` maps pin NAME to net name. A pin whose name is absent, or maps
    to None, gets a real NoConnect item rather than being left dangling -
    same rule the unused X1 pins follow.
    """
    place(lib_id, ref, value, x, y, body_h=generic_heights[lib_id])
    for num, name, etype in generic_pins[lib_id]:
        dx, dy = generic_offsets[(lib_id, num)]
        px, py = snap(x + dx), snap(y - dy)
        net = nets.get(name)
        if net is not None and etype == "power_out":
            driven_nets.add(net)
        if net is None:
            sch.noConnects.append(NoConnect(position=Position(px, py), uuid=U()))
            continue
        out = -1 if dx < 0 else 1
        wx, wy = snap(px + out * STUB), py
        for pt in ((px, py), (wx, wy)):
            prev = net_points.get(pt)
            if prev and prev[0] != net:
                print(f"  ERROR: {pt} carries both {prev[0]} (via {prev[1]}) "
                      f"and {net} (via {ref})")
            net_points[pt] = (net, ref)
        add_wire(px, py, wx, wy)
        if net in POWER_NETS:
            place(rail(net), f"#PWR_{ref}_{num}", net, wx, wy, hide_ref=True)
            power_net_points.setdefault(net, (wx, wy))
        else:
            add_label(net, wx, wy, 0 if out > 0 else 180)


def add_label(text, x, y, angle):
    assert text not in POWER_NETS, \
        f"power net {text} must use a power symbol, not a label"
    sch.labels.append(LocalLabel(
        text=text, position=Position(snap(x), snap(y), angle),
        effects=Effects(font=Font(width=1.27, height=1.27),
                        justify=Justify(horizontally="left")),
        uuid=U()))


def build_common_symbols():
    """
    The generic two- and three-terminal parts every block reuses.

    Built once, before any section runs. They used to be created inside
    build_power_tree(), which worked only while that happened to be the
    first block called - reordering the sections turned it into a
    KeyError. Shared state belongs at the top, not in whichever caller
    ran first.
    """
    build_generic_symbol(f"{LIB}:R", "R", "R", PASSIVE_PINS)
    build_generic_symbol(f"{LIB}:C", "C", "C", PASSIVE_PINS)
    build_generic_symbol(f"{LIB}:L", "L", "L", PASSIVE_PINS)
    build_generic_symbol(f"{LIB}:TVS", "D", "TVS", PASSIVE_PINS)
    build_generic_symbol(f"{LIB}:FUSE", "F", "Fuse", PASSIVE_PINS)
    build_generic_symbol(f"{LIB}:NFET", "Q", "NFET", NFET_PINS)
    build_generic_symbol(f"{LIB}:TLV767-Q1", "U", "TLV767-Q1", parts.TLV767_Q1)
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

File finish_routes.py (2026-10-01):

#!/usr/bin/env python3
"""
finish_routes.py - route the connections FreeRouting leaves open.

route_board.py gets most of the way and then stalls on a handful of nets
(150 passes left 3; a second run left 1 by its own count and 8 by DRC, so
restarting is a coin flip). This finishes them deterministically: for each
connection kicad-cli DRC reports as open, it runs an A* search through the
actual copper on the board and lays down real tracks and vias. When a pad is
walled in, it rips up the tracks boxing it in, routes the stuck net, and
reroutes whatever it ripped on the next round.

How it works, and why it is shaped this way:

  * The board is rasterised to a 0.05 mm grid, one boolean "blocked" layer
    per copper layer. Every pad, track and via NOT on the net being routed
    is stamped with its own size plus the 0.2 mm clearance; the result is
    then grown by half a track width (for tracks) or by a via's radius (for
    vias), so a free cell really is a legal centre line. Items on the net
    itself are skipped - touching your own copper is the point.
  * Search is 8-direction on each layer with through-vias between them.
    Vias are only allowed where every layer is clear at via size, which is
    what a through via actually needs. A via costs as much as 3 mm of track,
    so it is used to get out of a jam and not as a habit.
  * Fine-pitch pads are reachable because the search starts from the grid
    node nearest the true pad centre, and the first and last segments run
    from the pad centre to that node (at most 0.035 mm).
  * A pad can be sealed in. On this board the three connections FreeRouting
    could not finish were all fine-pitch QFP pads whose neighbours' fan-out
    tracks left a single-cell corridor that ended at a wall; a flood fill
    from U9.28 reached only the pad's own 1.55 mm length. So pads and the
    board edge are HARD keep-outs, and other nets' tracks and vias are SOFT:
    the search may cross them at a price (SOFT_PENALTY per cell), and only
    the copper the chosen path actually crosses is ripped up. The next round
    reads the newly opened connections from DRC and routes those.
  * STATUS: this does not converge on Fascia. Open connections went
    3 -> 17 -> 16 -> 21 over four rounds (an earlier version that ripped
    everything near the pocket went 3 -> 20 -> 20), because re-laying a
    ripped net crosses something else. So the driver compares DRC before
    and after and RESTORES THE ORIGINAL BOARD unless the result is strictly
    better. It is kept because the A* core, the sealed-pad diagnosis and the
    safety net are all sound, and because it may work on a less congested
    board; see PLAN.md for what to do about this one.
  * Zones are NOT treated as obstacles. A new track through a GND pour just
    gets a clearance cut when the pour is refilled, so the zones are removed
    before routing and rebuilt afterwards by route_board.add_and_fill_zones()
    (one per process - see that function for why). That also means DRC has
    to be read after the pours are back, or every GND pad looks open.

The grid is an approximation; the real check is kicad-cli DRC afterwards,
which this script runs and reports. It does not length-match anything.

Usage:  python finish_routes.py
"""
import heapq
import json
import math
import os
import re
import subprocess
import sys

HERE = os.path.dirname(os.path.abspath(__file__))
PCB = os.path.join(HERE, "Fascia.kicad_pcb")
PAIRS = os.path.join(os.environ.get("TEMP", HERE), "fascia_open_pairs.json")

RES = 0.05           # grid pitch, mm
TRACK_W = 0.2        # Default class width
CLEARANCE = 0.22     # kicad-cli enforces 0.2; the extra 0.02 absorbs grid rounding
VIA_D, VIA_DRILL = 0.6, 0.3
EDGE_CLEAR = 0.5     # min_copper_edge_clearance
VIA_COST = 3.0       # mm of track a via is worth
QUICK_CAP = 300_000  # expansions before a search is called "not obviously sealed"
MAX_EXPANSIONS = 15_000_000
SOFT_PENALTY = 0.4   # mm-equivalent charged per cell of crossing another net's track
RIP_MARGIN = 0.03    # mm of extra reach when deciding what a new path has crossed
MAX_ROUNDS = int(os.environ.get("FINISH_ROUNDS", 8))

PAD_RE = re.compile(r"(?:PTH |SMD )?[Pp]ad ([^ ]+) \[([^\]]+)\] of ([^ ]+)")
TRACK_RE = re.compile(r"Track \[([^\]]+)\]")
VIA_RE = re.compile(r"Via \[([^\]]+)\]")


# ---------------------------------------------------------------------------
# Driver (system Python): find the open connections, run the router under
# KiCad's Python, rebuild the zones, read DRC again, repeat.
# ---------------------------------------------------------------------------
def classify(item):
    """One DRC item -> {"kind", "net", ...} or None if it is not routable
    copper (a zone, for instance)."""
    desc = item.get("description", "")
    m = PAD_RE.search(desc)
    if m:
        return {"kind": "pad", "net": m.group(2), "num": m.group(1),
                "ref": m.group(3), "uuid": item.get("uuid")}
    m = TRACK_RE.search(desc)
    if m:
        return {"kind": "track", "net": m.group(1), "uuid": item.get("uuid")}
    m = VIA_RE.search(desc)
    if m:
        return {"kind": "via", "net": m.group(1), "uuid": item.get("uuid")}
    return None


def open_pairs():
    import route_board as rb
    report = os.path.join(os.environ.get("TEMP", HERE), "finish_routes_drc.json")
    subprocess.run([rb.find_kicad_cli(), "pcb", "drc", "--format", "json",
                    "--output", report, PCB], capture_output=True, text=True)
    drc = json.load(open(report, encoding="utf-8"))
    pairs, skipped = [], []
    for u in drc.get("unconnected_items", []):
        items = [classify(i) for i in u["items"]]
        if len(items) == 2 and all(items) and items[0]["net"] == items[1]["net"]:
            pairs.append({"net": items[0]["net"], "a": items[0], "b": items[1]})
        else:
            skipped.append([i.get("description", "") for i in u["items"]])
    return pairs, skipped


EXPECTED_VIOLATIONS = {"unconnected_items", "lib_footprint_mismatch"}


def drc_counts():
    """(unconnected items, real violations) straight from kicad-cli. Real
    means anything outside the two categories run_drc.py treats as expected,
    and it matters here because a router that closes connections by
    crowding copper has not finished anything."""
    import route_board as rb
    report = os.path.join(os.environ.get("TEMP", HERE), "finish_routes_count.json")
    subprocess.run([rb.find_kicad_cli(), "pcb", "drc", "--format", "json",
                    "--output", report, PCB], capture_output=True, text=True)
    drc = json.load(open(report, encoding="utf-8"))
    real = [v for v in drc.get("violations", [])
            if v.get("type") not in EXPECTED_VIOLATIONS]
    return len(drc.get("unconnected_items", [])), len(real)


def label(it):
    return f"{it['ref']}.{it['num']}" if it["kind"] == "pad" else it["kind"]
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

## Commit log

2026-08-16 Add Fascia: Verdin iMX95 carrier for a 10in Android Automotive display
    Fourth board in the family, sibling to Manifold/ECU/Thermo. A 10-inch
    Android Automotive touch head unit, split across two boards because the
    panel sits 20cm-1m away across the dash.
    Research and verified data only - no schematic or PCB yet.
    Design decisions, with the reasoning recorded in README.md:
    - i.MX 93 rejected. It has no 3D GPU, and NXP has excluded GPU-less i.MX
    parts from Android support since Android 10, so it cannot run Android
    Automotive at all. Replaced with i.MX 95 (Mali-G310).
    - Verdin iMX95 SoM on a custom carrier rather than a raw BGA: raw would
    mean ~90 hand-matched LPDDR5 nets, and FreeRoutin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
2026-08-16 Confirm the DSI link closes: i.MX 95 does 2.5 Gbps/lane, bridge is the limit
    Closes the one open question that could have invalidated the 1920x1200
    target, using the i.MX 95 automotive datasheet (IMX95AEC Rev 8) and
    hardware design guide (UG10210 Rev 2.0).
    The SoC side turns out to be a non-issue. Table 58 gives RATE[TX] =
    80 to 2500 Mbps per lane, and the feature summary lists "1x 350 MHz
    MIPI-DSI (4-lane, 2.5 Gbps/lane) supporting 4kp30 or 3840 x 1440p60".
    This design needs ~925 Mbps/lane, so ~37% of capability.
    That makes the SN65DSI85-Q1's 1 Gbps/lane DSI input the sole bottleneck
    in the chain, at ~93%. Still fits - TI documents 1920x1200 as a
    supported case - but it means the bridge,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
2026-08-16 Panel research: iFan IF101GRL192-120B leads; touch may need USB not I2C
    Surveyed the real 10.1" market against the target spec (1920x1200,
    1000 nit, optically bonded, PCAP, automotive temp).
    Leading candidate is the iFan IF101GRL192-120B: 1920x1200, 1000 nit,
    LVDS 60-pin, PCAP touch included, -30 to +80 C, 1100:1, AHVA, 89%
    DCI-P3, antiglare 3H hard coat. Optical bonding is unconfirmed and
    there's no public datasheet, so it's a contact-the-vendor part - the
    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
2026-08-16 Select the iFan panel; bank the 260-pin X1 connector into symbol units
    Panel decision: iFan IF101GRL192-120B, chosen mainly on temperature
    (-30 to +80 C, a full 10 C better at both ends than the other 1920x1200
    candidate, which is the difference between reliable and marginal on a
    sun-baked dash), with 89% DCI-P3 gamut as a real bonus for image
    quality. Datasheet and pricing requested from the vendor; until that
    arrives the backlight converter, panel connector, touch link and
    mechanical all stay blocked, and the README says so explicitly.
    Adds verdin_x1.py, which solves a problem that has to be settled before
    any schematic work: a 260-pin connector cannot be one symbol, since at
    2.54 mm pitc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
    [verdin_x1.py]
2026-08-16 Generate the schematic: Verdin X1 connector, ERC down to 50 expected findings
    Adds build_schematic.py, which produces a real KiCad-loadable schematic
    containing the 260-pin Verdin iMX95 X1 connector as a multi-unit symbol,
    plus Fascia.kicad_sym, sym-lib-table, and (first run only) a minimal
    Fascia.kicad_pro.
    Final at this stage: all 260 pins exist across 6 units, 47 GND tied to
    ground, 5 VCC tied to +5V with PWR_FLAGs on both rails since no
    regulator is on the sheet yet, and 158 unused pins carrying real
    NoConnect items.
    kicad-cli sch erc reports 50 violations, all pin_not_connected, and that
    is the correct result here - they are exactly the control, display and
    communications pins that th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
    [Fascia.kicad_sch]
2026-08-16 Select and verify the power-tree and CAN parts against their datasheets
    No schematic change yet - this records the part selection with evidence,
    so the next increment can wire it without re-litigating the choices.
    Selected, each verified against its own datasheet:
    LM74930-Q1 front-end protection - AEC-Q100 grade 1, 4-65 V in,
    reverse protection to -65 V, adjustable OC/OV, circuit
    breaker, meets ISO7637 with a suitable TVS
    LM61460-Q1 12 V -> 5 V buck - AEC-Q100 grade 1, 3-36 V in (42 V
    transient), 6 A, synchronous, low-EMI spread spectrum
    TCAN1044V-Q1 CAN FD - AEC-Q100 grade 1, VIO 1.7-5.5 V with explicit
    1.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
2026-08-16 Revise scope: audio pre-outs, microphone, USB-C CarPlay; Bluetooth is free
    Scope change from the user: this is a screen and audio source, not an
    amplifier. It drives no speakers - it feeds an existing automotive amp
    over line-level pre-outs. Adds Bluetooth, a microphone, and USB-C for
    wired CarPlay / Android Auto with phone charging.
    Keeping the power amplifier off the board is the important half of that
    decision: it removes the highest-current, highest-heat, highest-EMI
    subsystem from a sealed dash enclosure that already has a 1000-nit
    backlight in it.
    New parts, each verified against its datasheet:
    PCM3168A-Q1 AEC-Q100 24-bit 6-in/8-out audio codec, differential
    outp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
    [Fascia.kicad_sch]
2026-08-16 Add verified part pinouts; correct the LM74930-Q1 overvoltage claim
    Adds parts.py holding datasheet-verified pinouts for the LM74930-Q1
    (VQFN-24, TI SNOSDF6) and TCAN1044V-Q1 (SOIC-8, TI SLLSF17D), in the
    form the symbol factory consumes, with a verifier that asserts pin
    counts and contiguous numbering so a careless edit is caught before it
    reaches a netlist.
    Corrects a claim I made two commits ago. I wrote that the LM74930-Q1
    protects against overvoltage only by disconnecting the load, and warned
    that a load dump would therefore collapse the 5 V rail and force an
    Android reboot. That was wrong. Reading the pin and spec tables:
    - pin 16 is OVCLAMP, "connect this pin to OV pin for overvolta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
    [parts.py]
2026-08-16 Add LM61460-Q1 pinout and resolve the LM74930-Q1 FET topology
    Completes the datasheet work needed before the power tree can be wired.
    LM61460-Q1 (VQFN-HR-14, TI SNVSB70F) added to parts.py with three
    gotchas recorded inline:
    - BIAS (1) is not a bypass pin. It feeds the internal LDO and ties to
    the OUTPUT rail for efficiency, but only while Vout <= 12 V; above
    that it goes to ground. At 5 V out it goes to the output.
    - FB (4), RT (6) and EN/SYNC (7) must neither float nor be grounded.
    Grounding RT is the easy mistake, since most "set by a resistor to
    ground" pins tolerate being tied down.
    - AGND (3) must connect to BOTH PGND1 (9) and PGND2 (11), and the
    VIN1/VIN2 and PGND1/PGND2 p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
    [Fascia.kicad_sch]
2026-08-16 Wire the power tree: LM74930-Q1 front end and LM61460-Q1 5 V buck
    Both regulators are now fully wired, with every pin either netted or
    explicitly NoConnected. ERC sits at 51 findings, all expected: the 50 X1
    pins awaiting the bridge/transceiver/codec/panel blocks, plus IGN_SENSE,
    which has no destination until the ignition-sense path reaches a module
    ADC pin.
    Front end follows TI's own reference circuit for the part, "VBAT 12-V or
    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
    [Fascia.kicad_sch]
2026-08-21 Wire the 1.8 V rail and the CAN FD link to ecu-pcb
    Adds the TLV767-Q1 1.8 V LDO and the TCAN1044V-Q1 CAN transceiver, and
    connects the module's CAN_1_TX / CAN_1_RX to them. ERC drops from 51 to
    49 findings, still all expected: 48 X1 pins awaiting the bridge, codec
    and panel connector, plus IGN_SENSE.
    The 1.8 V rail exists because the Verdin's I/O is 1.8 V logic. An LDO
    rather than a buck on purpose - the load is small, and a linear
    regulator adds no switching noise to a board carrying LVDS next to a car
    radio. It feeds the transceiver's VIO now and the SN65DSI85-Q1 bridge
    later.
    CAN uses split termination - 2x60 ohm with a midpoint capacitor to
    ground - rather than a single 120 ohm, becaus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
    [Fascia.kicad_sch]
2026-08-21 Wire the SN65DSI85-Q1 bridge: the display path is complete end to end
    Adds the DSI-to-LVDS bridge and a provisional panel connector, and
    connects the module's full DSI link to it. ERC drops from 49 to 37,
    still all expected.
    The milestone is the display bank: it is down from 15 unconnected pins
    to 2. The whole path from the module's MIPI DSI, through the bridge, out
    as dual-link LVDS to the panel connector, is wired. The only thing
    missing from it is the backlight - PWM_3_DSI and GPIO_10_DSI - which
    cannot be designed until iFan send the string voltage and current.
    Configured for datasheet Table 5 "Single DSI Input to Dual-Link LVDS":
    DSI channel A, four lanes, odd pixels on LVDS link A an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
    [Fascia.kicad_sch]
2026-08-21 Wire the audio block; catch a codec/module logic-level incompatibility
    Adds the PCM3168A-Q1 codec, a 3.3 V rail, two SN74AXC4T245-Q1 level
    shifters and the pre-out and microphone connectors. ERC 37 -> 35, and
    bank D is down to just USB-C and the second CAN.
    The finding that shaped this block: the codec's digital domain is
    3.0-3.6 V and cannot be run at 1.8 V. Its VIH minimum is 2 V, above what
    a 1.8 V output can guarantee - and its VOH minimum is 2.4 V, above the
    module's 2.1 V ABSOLUTE MAXIMUM on 1.8 V I/O. Wired directly, the
    codec-to-module direction would have damaged the module. Every digital
    line between them is now translated.
    I2S and clocks go through SN74AXC4T245-Q1 (AEC-Q100, 0.6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
    [Fascia.kicad_sch]
2026-08-21 Wire the USB-C port; catch a second silent net merge
    Adds the USB-C port for wired CarPlay / Android Auto. ERC 35 -> 29, and
    bank D is down to the panel touch link and the second CAN.
    TPS2557-Q1 switches VBUS with a ~3.3 A limit, leaving margin over the
    3 A advertised by the Rp resistors on CC1 and CC2. Both CC pins are
    populated because Type-C is reversible. ID is strapped low for host
    mode, VBUS sense is divided down to stay inside 1.8 V logic, and every
    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
    [Fascia.kicad_sch]
2026-08-21 Wire control, sequencing and RTC backup; ERC down to 10 blocked items
    Adds the JTAG header, power/recovery/reset buttons and the RTC coin
    cell, and completes bank B. ERC 29 -> 10, and every remaining finding is
    either blocked on a datasheet that has not arrived or deliberately
    optional:
    2 PWM_3_DSI, GPIO_10_DSI backlight, needs the iFan string V/I
    4 USB_2_* panel touch link, needs the touch
    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
    [Fascia.kicad_sch]
2026-08-21 Assign and verify footprints; make exposed-pad handling explicit
    Every part except one now carries a KiCad library footprint, and
    build_schematic.py verifies at build time that each named file actually
    exists. A mistyped library path is otherwise invisible until the netlist
    reaches the PCB editor and silently drops the part.
    The biggest footprint risk turned out to be none at all: the Verdin
    plugs into a standard DDR4 SODIMM socket, and KiCad's
    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
    [Fascia.kicad_sch]
2026-08-21 Generate the LM61460-Q1 VQFN-HR-14 footprint; every part now has one
    TI's RJR0014A has no KiCad library footprint and is not something a
    generic QFN generator can produce: the pads are all different sizes,
    unevenly spaced, and the four corner pads are L-shaped. This was the last
    thing blocking the PCB.
    Geometry is not eyeballed off the drawing. The LAND PATTERN EXAMPLE on
    page 55 of TI SNVSB70F is real vector art, so the pad rectangles were
    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
    [Fascia.kicad_sch]
2026-08-21 Start the PCB: 118 parts placed and netted, schematic parity clean
    Adds build_pcb.py and run_drc.py. The board now exists: 118 footprints,
    574 pads netted across 129 nets, six layers, 148 x 164 mm. Nothing is
    routed - route_board.py is next.
    Ground truth comes from outside this script, deliberately. The parts list
    is read out of the schematic file and the net assignments come from
    kicad-cli's own netlist export, so drift between schematic and PCB fails
    here rather than producing a quietly wrong board. That check is already
    earning its keep: DRC reports schematic parity 0.
    Six layers rather than four - the DSI and LVDS pairs each want a
    reference plane beside them, and the audio section wan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
    [Fascia.kicad_pcb, Fascia.kicad_sch]
2026-08-22 Rotate the socket and group parts functionally: 164mm tall -> 92mm
    Two changes, both prompted by the board looking like a parts bin.
    The Verdin socket is now rotated 90 degrees. Its footprint is 36 x 79 mm,
    tall and narrow, which forced a tall board and wasted the space beside
    it. On its side it is 79 x 36 mm, the board becomes landscape - which is
    also the shape a dash opening wants - and the height drops from 164 mm to
    92 mm.
    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
    [Fascia.kicad_pcb]
2026-08-23 Port the sibling skyline packer: board 179x92 -> 148x64
    You were right that I had forgotten how we placed the other boards. This
    replaces my shelf packer with the skyline bottom-left packer manifold-pcb
    and thermo-pcb already use, ported rather than reinvented.
    Two properties of that packer do the work, and my version had neither:
    - Every part is tried BOTH unrotated and rotated 90 degrees, and goes
    wherever it yields the lowest top edge. That is what turns the tall
    pin-header connectors on their sides - 16 parts end up rotated - and
    lets the 0603s backfill the low spots beside big parts instead of being
    confined to a same-size block.
    - Candidate positions include right-justifying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
    [Fascia.kicad_pcb]
2026-09-30 Port route_board.py from the siblings: FreeRouting pipeline, trunk widening, GND pours, real-DRC check
    Retargeted at Fascia's files, nets and 6-layer stack (GND on In1 and In4,
    In2/In3 left for routing). Trunk nets and width ladder live in build_pcb.py.
    Adds a fresh-board guard and an intra-pair skew report for the DSI/LVDS/USB/CAN
    pairs. Not yet run to completion: 10 passes take 445 unrouted nets to 17.
    [Fascia.kicad_pcb]
2026-09-30 Route Fascia to within 3 connections: bridge beside socket, passives near their IC
    Area-ordered skyline placement put the DSI bridge 75 mm from the Verdin
    socket and scattered passives far from their ICs (REFCLK_GND resistor 130 mm
    from U5). PIN_FIRST places bridge/socket/panel connector first; PULL makes a
    passive take the slot nearest its anchor IC. HPWL 7612 -> 5895 mm; FreeRouting
    at 12 passes 22 -> 4 unrouted. CLEAR 1.3 -> 2.0.
    150-pass run leaves 3 open (AOUT_RL_N, U9_ADR1_TIE, LVDS_A_Y0N), confirmed by
    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
    [Fascia.kicad_pcb]
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2026-09-30 finish_routes.py: rip-up, sealed-pad detection, and a restore-if-worse safety net
    The three connections FreeRouting cannot close are pads sealed in by their
    neighbours' fan-out. The finisher now detects that, rips up the copper walling
    a pad in, routes the stuck net, and rereads DRC each round. It does route all
    three, but ripping up opens 17 more and the rounds do not converge (20 open,
    25-45 real clearance violations), so the script compares DRC before and after
    and restores the original board if the result is not strictly better. The
    restore path was exercised: it fires.
    PLAN.md records the findings and recommends hand-routing the last three.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
    [finish_routes.py]
2026-10-01 finish_routes.py: negotiated soft-obstacle routing; record that it does not converge
    Pads and the board edge are hard keep-outs, other nets' tracks and vias are
    soft: the search crosses them at a cost and only the copper the path crosses
    is ripped up. Did not converge on Fascia either (3 -> 17 -> 16 -> 21 open,
    59 real violations); the restore-if-worse safety net put the original board
    back. CLEARANCE is 0.22 to absorb grid rounding. PLAN.md records both
    attempts and recommends giving U9 and U5 more room or hand-routing the last
    three.
    [finish_routes.py]
